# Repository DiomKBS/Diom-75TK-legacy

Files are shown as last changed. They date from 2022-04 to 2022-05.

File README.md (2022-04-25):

# full-board-shorter
a keyboard with 75% layout that has macrokeys and a numpad

## The current design:
current design

## You can visit the whiteboard over at Milanote:
Link --> [Whiteboard](https://app.milanote.com/1NjfUT1bPf1Z3v?p=4XtU1EYbywI)

pcb
pcb_back

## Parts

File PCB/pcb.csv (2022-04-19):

Source: | C:\Users\Philipp Bleimund\git\repository\Diom-75TK\PCB\pcb.kicad_sch
Date: | 20.04.2022 00:11:18
Tool: | Eeschema (6.0.4)
Generator: | C:\Program Files\KiCad\6.0\bin\scripting\plugins/bom_csv_grouped_by_value.py
Component Count: | 324
Individual Components:
Item | Qty | Reference(s) | Value | LibPart | Footprint | Datasheet | Item | LCSC | Name
 |  | C1 | 10u | Device:C_Small | Capacitor_SMD:C_0805_2012Metric | ~
 |  | C2 | 0.1uF | Device:C_Small | Capacitor_SMD:C_0805_2012Metric | ~
 |  | C3 | 0.1uF | Device:C_Small | Capacitor_SMD:C_0805_2012Metric | ~
 |  | C4 | 0.1uF | Device:C_Small | Capacitor_SMD:C_0805_2012Metric | ~
 |  | C5 | 22pF | Device:C_Small | Capacitor_SMD:C_0805_2012Metric | ~
 |  | C6 | 22pF | Device:C_Small | Capacitor_SMD:C_0805_2012Metric | ~
 |  | C7 | 10uF | Device:C_Small | Capacitor_SMD:C_0805_2012Metric | ~
 |  | C8 | 1uF | Device:C_Small | Capacitor_SMD:C_0805_2012Metric | ~
 |  | D1 | 1.25V@150mA | led:D_Small | led:D_SOD-123 | ~ | 1N4148W | https://lcsc.com/product-detail/Switching-Diode_GOODWORK-1N4148W_C909967.html | Esc
 |  | D2 | 1.25V@150mA | Device:D_Small | led:D_SOD-123 | ~ |  |  | ^
 |  | D3 | 1.25V@150mA | Device:D_Small | led:D_SOD-123 | ~ |  |  | Tab
 |  | D4 | 1.25V@150mA | Device:D_Small | led:D_SOD-123 | ~ |  |  | Caps
 |  | D5 | 1.25V@150mA | Device:D_Small | led:D_SOD-123 | ~ |  |  | Shift
 |  | D6 | 1.25V@150mA | Device:D_Small | led:D_SOD-123 | ~ |  |  | Ctrl
 |  | D7 | 1.25V@150mA | Device:D_Small | led:D_SOD-123 | ~ |  |  | 1
 |  | D8 | 1.25V@150mA | Device:D_Small | led:D_SOD-123 | ~ |  |  | Q
 |  | D9 | 1.25V@150mA | Device:D_Small | led:D_SOD-123 | ~ |  |  | A
 |  | D10 | 1.25V@150mA | Device:D_Small | led:D_SOD-123 | ~ |  |  | <
 |  | D11 | 1.25V@150mA | Device:D_Small | led:D_SOD-123 | ~ |  |  | Win
 |  | D12 | 1.25V@150mA | Device:D_Small | led:D_SOD-123 | ~ |  |  | F1
 |  | D13 | 1.25V@150mA | Device:D_Small | led:D_SOD-123 | ~ |  |  | 2
 |  | D14 | 1.25V@150mA | Device:D_Small | led:D_SOD-123 | ~ |  |  | W
 |  | D15 | 1.25V@150mA | Device:D_Small | led:D_SOD-123 | ~ |  |  | S
 |  | D16 | 1.25V@150mA | Device:D_Small | led:D_SOD-123 | ~ |  |  | Y
 |  | D17 | 1.25V@150mA | Device:D_Small | led:D_SOD-123 | ~ |  |  | Alt
 |  | D18 | 1.25V@150mA | Device:D_Small | led:D_SOD-123 | ~ |  |  | F2
 |  | D19 | 1.25V@150mA | Device:D_Small | led:D_SOD-123 | ~ |  |  | 3
 |  | D20 | 1.25V@150mA | Device:D_Small | led:D_SOD-123 | ~ |  |  | E
 |  | D21 | 1.25V@150mA | Device:D_Small | led:D_SOD-123 | ~ |  |  | D
 |  | D22 | 1.25V@150mA | Device:D_Small | led:D_SOD-123 | ~ |  |  | X
 |  | D23 | 1.25V@150mA | Device:D_Small | led:D_SOD-123 | ~ |  |  | F3
 |  | D24 | 1.25V@150mA | Device:D_Small | led:D_SOD-123 | ~ |  |  | 4
 |  | D25 | 1.25V@150mA | Device:D_Small | led:D_SOD-123 | ~ |  |  | R
 |  | D26 | 1.25V@150mA | Device:D_Small | led:D_SOD-123 | ~ |  |  | F
 |  | D27 | 1.25V@150mA | Device:D_Small | led:D_SOD-123 | ~ |  |  | C
 |  | D28 | 1.25V@150mA | Device:D_Small | led:D_SOD-123 | ~ |  |  | F4
 |  | D29 | 1.25V@150mA | Device:D_Small | led:D_SOD-123 | ~ |  |  | 5
 |  | D30 | 1.25V@150mA | Device:D_Small | led:D_SOD-123 | ~ |  |  | T
 |  | D31 | 1.25V@150mA | Device:D_Small | led:D_SOD-123 | ~ |  |  | G
 |  | D32 | 1.25V@150mA | Device:D_Small | led:D_SOD-123 | ~ |  |  | V
 |  | D33 | 1.25V@150mA | Device:D_Small | led:D_SOD-123 | ~ |  |  | F5
 |  | D34 | 1.25V@150mA | Device:D_Small | led:D_SOD-123 | ~ |  |  | 6
 |  | D35 | 1.25V@150mA | Device:D_Small | led:D_SOD-123 | ~ |  |  | Z
 |  | D36 | 1.25V@150mA | Device:D_Small | led:D_SOD-123 | ~ |  |  | H
 |  | D37 | 1.25V@150mA | Device:D_Small | led:D_SOD-123 | ~ |  |  | B
 |  | D38 | 1.25V@150mA | Device:D_Small | led:D_SOD-123 | ~ |  |  | Space
 |  | D39 | 1.25V@150mA | Device:D_Small | led:D_SOD-123 | ~ |  |  | F6
 |  | D40 | 1.25V@150mA | Device:D_Small | led:D_SOD-123 | ~ |  |  | 7
 |  | D41 | 1.25V@150mA | Device:D_Small | led:D_SOD-123 | ~ |  |  | U
 |  | D42 | 1.25V@150mA | Device:D_Small | led:D_SOD-123 | ~ |  |  | J
 |  | D43 | 1.25V@150mA | Device:D_Small | led:D_SOD-123 | ~ |  |  | N
 |  | D44 | 1.25V@150mA | Device:D_Small | led:D_SOD-123 | ~ |  |  | F7
 |  | D45 | 1.25V@150mA | Device:D_Small | led:D_SOD-123 | ~ |  |  | 8
 |  | D46 | 1.25V@150mA | Device:D_Small | led:D_SOD-123 | ~ |  |  | I
 |  | D47 | 1.25V@150mA | Device:D_Small | led:D_SOD-123 | ~ |  |  | K
 |  | D48 | 1.25V@150mA | Device:D_Small | led:D_SOD-123 | ~ |  |  | M
 |  | D49 | 1.25V@150mA | Device:D_Small | led:D_SOD-123 | ~ |  |  | F8
 |  | D50 | 1.25V@150mA | Device:D_Small | led:D_SOD-123 | ~ |  |  | 9
 |  | D51 | 1.25V@150mA | Device:D_Small | led:D_SOD-123 | ~ |  |  | O
 |  | D52 | 1.25V@150mA | Device:D_Small | led:D_SOD-123 | ~ |  |  | L
 |  | D53 | 1.25V@150mA | Device:D_Small | led:D_SOD-123 | ~ |  |  | ,
 |  | D54 | 1.25V@150mA | Device:D_Small | led:D_SOD-123 | ~ |  |  | F9
 |  | D55 | 1.25V@150mA | Device:D_Small | led:D_SOD-123 | ~ |  |  | 0
 |  | D56 | 1.25V@150mA | Device:D_Small | led:D_SOD-123 | ~ |  |  | P
 |  | D57 | 1.25V@150mA | Device:D_Small | led:D_SOD-123 | ~ |  |  | Ö
 |  | D58 | 1.25V@150mA | Device:D_Small | led:D_SOD-123 | ~ |  |  | .
 |  | D59 | 1.25V@150mA | Device:D_Small | led:D_SOD-123 | ~ |  |  | AltGr
 |  | D60 | 1.25V@150mA | Device:D_Small | led:D_SOD-123 | ~ |  |  | F10
 |  | D61 | 1.25V@150mA | Device:D_Small | led:D_SOD-123 | ~ |  |  | ß
 |  | D62 | 1.25V@150mA | Device:D_Small | led:D_SOD-123 | ~ |  |  | Ü
 |  | D63 | 1.25V@150mA | Device:D_Small | led:D_SOD-123 | ~ |  |  | Ä
 |  | D64 | 1.25V@150mA | Device:D_Small | led:D_SOD-123 | ~ |  |  | -
 |  | D65 | 1.25V@150mA | Device:D_Small | led:D_SOD-123 | ~ |  |  | Fn
 |  | D66 | 1.25V@150mA | Device:D_Small | led:D_SOD-123 | ~ |  |  | F11
 |  | D67 | 1.25V@150mA | Device:D_Small | led:D_SOD-123 | ~ |  |  | ´
 |  | D68 | 1.25V@150mA | Device:D_Small | led:D_SOD-123 | ~ |  |  | +
 |  | D69 | 1.25V@150mA | Device:D_Small | led:D_SOD-123 | ~ |  |  | #
 |  | D70 | 1.25V@150mA | Device:D_Small | led:D_SOD-123 | ~ |  |  | Shift
 |  | D71 | 1.25V@150mA | Device:D_Small | led:D_SOD-123 | ~ |  |  | Win
 |  | D72 | 1.25V@150mA | Device:D_Small | led:D_SOD-123 | ~ |  |  | F12
 |  | D73 | 1.25V@150mA | Device:D_Small | led:D_SOD-123 | ~ |  |  | Back
 |  | D74 | 1.25V@150mA | Device:D_Small | led:D_SOD-123 | ~ |  |  | Enter
 |  | D75 | 1.25V@150mA | Device:D_Small | led:D_SOD-123 | ~ |  |  | Left
 |  | D76 | 1.25V@150mA | Device:D_Small | led:D_SOD-123 | ~ |  |  | Up
 |  | D77 | 1.25V@150mA | Device:D_Small | led:D_SOD-123 | ~ |  |  | Down
 |  | D78 | 1.25V@150mA | Device:D_Small | led:D_SOD-123 | ~ |  |  | Rigth
 |  | D79 | 1.25V@150mA | Device:D_Small | led:D_SOD-123 | ~ |  |  | Druck
 |  | D80 | 1.25V@150mA | Device:D_Small | led:D_SOD-123 | ~ |  |  | Insert
 |  | D81 | 1.25V@150mA | Device:D_Small | led:D_SOD-123 | ~ |  |  | Del
 |  | D82 | 1.25V@150mA | Device:D_Small | led:D_SOD-123 | ~ |  |  | PgUp
 |  | D83 | 1.25V@150mA | Device:D_Small | led:D_SOD-123 | ~ |  |  | PgDn
 |  | D84 | 1.25V@150mA | Device:D_Small | led:D_SOD-123 | ~ |  |  | NumLock
 |  | D85 | 1.25V@150mA | Device:D_Small | led:D_SOD-123 | ~ |  |  | 7
 |  | D86 | 1.25V@150mA | Device:D_Small | led:D_SOD-123 | ~ |  |  | 4
 |  | D87 | 1.25V@150mA | Device:D_Small | led:D_SOD-123 | ~ |  |  | 1
 |  | D88 | 1.25V@150mA | Device:D_Small | led:D_SOD-123 | ~ |  |  | 0
 |  | D89 | 1.25V@150mA | Device:D_Small | led:D_SOD-123 | ~ |  |  | /
 |  | D90 | 1.25V@150mA | Device:D_Small | led:D_SOD-123 | ~ |  |  | 8
 |  | D91 | 1.25V@150mA | Device:D_Small | led:D_SOD-123 | ~ |  |  | 5
 |  | D92 | 1.25V@150mA | Device:D_Small | led:D_SOD-123 | ~ |  |  | 2
 |  | D93 | 1.25V@150mA | Device:D_Small | led:D_SOD-123 | ~ |  |  | ,
 |  | D94 | 1.25V@150mA | Device:D_Small | led:D_SOD-123 | ~ |  |  | *
 |  | D95 | 1.25V@150mA | Device:D_Small | led:D_SOD-123 | ~ |  |  | 9
 |  | D96 | 1.25V@150mA | Device:D_Small | led:D_SOD-123 | ~ |  |  | 6
 |  | D97 | 1.25V@150mA | Device:D_Small | led:D_SOD-123 | ~ |  |  | 3
 |  | D98 | 1.25V@150mA | Device:D_Small | led:D_SOD-123 | ~ |  |  | -
 |  | D99 | 1.25V@150mA | Device:D_Small | led:D_SOD-123 | ~ |  |  | +
 |  | D100 | 1.25V@150mA | Device:D_Small | led:D_SOD-123 | ~ |  |  | Enter
 |  | D101 | SK6812MINI | LED:SK6812MINI | led:SK6812MINI_3.5x3.7mm_SMD-Flipped-Back | https://cdn-shop.adafruit.com/product-files/2686/SK6812MINI_REV.01-1-2.pdf
 |  | D102 | SK6812MINI | LED:SK6812MINI | led:SK6812MINI_3.5x3.7mm_SMD-Flipped-Back | https://cdn-shop.adafruit.com/product-files/2686/SK6812MINI_REV.01-1-2.pdf
 |  | D103 | SK6812MINI | LED:SK6812MINI | led:SK6812MINI_3.5x3.7mm_SMD-Flipped-Back | https://cdn-shop.adafruit.com/product-files/2686/SK6812MINI_REV.01-1-2.pdf
 |  | D104 | SK6812MINI | LED:SK6812MINI | led:SK6812MINI_3.5x3.7mm_SMD-Flipped-Back | https://cdn-shop.adafruit.com/product-files/2686/SK6812MINI_REV.01-1-2.pdf
 |  | D105 | SK6812MINI | LED:SK6812MINI | led:SK6812MINI_3.5x3.7mm_SMD-Flipped-Back | https://cdn-shop.adafruit.com/product-files/2686/SK6812MINI_REV.01-1-2.pdf
 |  | D106 | SK6812MINI | LED:SK6812MINI | led:SK6812MINI_3.5x3.7mm_SMD-Flipped-Back | https://cdn-shop.adafruit.com/product-files/2686/SK6812MINI_REV.01-1-2.pdf
 |  | D107 | SK6812MINI | LED:SK6812MINI | led:SK6812MINI_3.5x3.7mm_SMD-Flipped-Back | https://cdn-shop.adafruit.com/product-files/2686/SK6812MINI_REV.01-1-2.pdf
 |  | D108 | SK6812MINI | LED:SK6812MINI | led:SK6812MINI_3.5x3.7mm_SMD-Flipped-Back | https://cdn-shop.adafruit.com/product-files/2686/SK6812MINI_REV.01-1-2.pdf
 |  | D109 | SK6812MINI | LED:SK6812MINI | led:SK6812MINI_3.5x3.7mm_SMD-Flipped-Back | https://cdn-shop.adafruit.com/product-files/2686/SK6812MINI_REV.01-1-2.pdf
 |  | D110 | SK6812MINI | LED:SK6812MINI | led:SK6812MINI_3.5x3.7mm_SMD-Flipped-Back | https://cdn-shop.adafruit.com/product-files/2686/SK6812MINI_REV.01-1-2.pdf
 |  | D111 | SK6812MINI | LED:SK6812MINI | led:SK6812MINI_3.5x3.7mm_SMD-Flipped-Back | https://cdn-shop.adafruit.com/product-files/2686/SK6812MINI_REV.01-1-2.pdf
 |  | D112 | SK6812MINI | LED:SK6812MINI | led:SK6812MINI_3.5x3.7mm_SMD-Flipped-Back | https://cdn-shop.adafruit.com/product-files/2686/SK6812MINI_REV.01-1-2.pdf
 |  | D113 | SK6812MINI | LED:SK6812MINI | led:SK6812MINI_3.5x3.7mm_SMD-Flipped-Back | https://cdn-shop.adafruit.com/product-files/2686/SK6812MINI_REV.01-1-2.pdf
 |  | D114 | SK6812MINI | LED:SK6812MINI | led:SK6812MINI_3.5x3.7mm_SMD-Flipped-Back | https://cdn-shop.adafruit.com/product-files/2686/SK6812MINI_REV.01-1-2.pdf
 |  | D115 | SK6812MINI | LED:SK6812MINI | led:SK6812MINI_3.5x3.7mm_SMD-Flipped-Back | https://cdn-shop.adafruit.com/product-files/2686/SK6812MINI_REV.01-1-2.pdf
 |  | D116 | SK6812MINI | LED:SK6812MINI | led:SK6812MINI_3.5x3.7mm_SMD-Flipped-Back | https://cdn-shop.adafruit.com/product-files/2686/SK6812MINI_REV.01-1-2.pdf
 |  | D117 | SK6812MINI | LED:SK6812MINI | led:SK6812MINI_3.5x3.7mm_SMD-Flipped-Back | https://cdn-shop.adafruit.com/product-files/2686/SK6812MINI_REV.01-1-2.pdf
 |  | D118 | SK6812MINI | LED:SK6812MINI | led:SK6812MINI_3.5x3.7mm_SMD-Flipped-Back | https://cdn-shop.adafruit.com/product-files/2686/SK6812MINI_REV.01-1-2.pdf
 |  | D119 | SK6812MINI | LED:SK6812MINI | led:SK6812MINI_3.5x3.7mm_SMD-Flipped-Back | https://cdn-shop.adafruit.com/product-files/2686/SK6812MINI_REV.01-1-2.pdf
 |  | D120 | SK6812MINI | LED:SK6812MINI | led:SK6812MINI_3.5x3.7mm_SMD-Flipped-Back | https://cdn-shop.adafruit.com/product-files/2686/SK6812MINI_REV.01-1-2.pdf
 |  | D121 | SK6812MINI | LED:SK6812MINI | led:SK6812MINI_3.5x3.7mm_SMD-Flipped-Back | https://cdn-shop.adafruit.com/product-files/2686/SK6812MINI_REV.01-1-2.pdf
 |  | D122 | SK6812MINI | LED:SK6812MINI | led:SK6812MINI_3.5x3.7mm_SMD-Flipped-Back | https://cdn-shop.adafruit.com/product-files/2686/SK6812MINI_REV.01-1-2.pdf
 |  | D123 | SK6812MINI | LED:SK6812MINI | led:SK6812MINI_3.5x3.7mm_SMD-Flipped-Back | https://cdn-shop.adafruit.com/product-files/2686/SK6812MINI_REV.01-1-2.pdf
 |  | D124 | SK6812MINI | LED:SK6812MINI | led:SK6812MINI_3.5x3.7mm_SMD-Flipped-Back | https://cdn-shop.adafruit.com/product-files/2686/SK6812MINI_REV.01-1-2.pdf
 |  | D125 | SK6812MINI | LED:SK6812MINI | led:SK6812MINI_3.5x3.7mm_SMD-Flipped-Back | https://cdn-shop.adafruit.com/product-files/2686/SK6812MINI_REV.01-1-2.pdf
 |  | D126 | SK6812MINI | LED:SK6812MINI | led:SK6812MINI_3.5x3.7mm_SMD-Flipped-Back | https://cdn-shop.adafruit.com/product-files/2686/SK6812MINI_REV.01-1-2.pdf
 |  | D127 | SK6812MINI | LED:SK6812MINI | led:SK6812MINI_3.5x3.7mm_SMD-Flipped-Back | https://cdn-shop.adafruit.com/product-files/2686/SK6812MINI_REV.01-1-2.pdf
 |  | D128 | SK6812MINI | LED:SK6812MINI | led:SK6812MINI_3.5x3.7mm_SMD-Flipped-Back | https://cdn-shop.adafruit.com/product-files/2686/SK6812MINI_REV.01-1-2.pdf
 |  | D129 | SK6812MINI | LED:SK6812MINI | led:SK6812MINI_3.5x3.7mm_SMD-Flipped-Back | https://cdn-shop.adafruit.com/product-files/2686/SK6812MINI_REV.01-1-2.pdf
 |  | D130 | SK6812MINI | LED:SK6812MINI | led:SK6812MINI_3.5x3.7mm_SMD-Flipped-Back | https://cdn-shop.adafruit.com/product-files/2686/SK6812MINI_REV.01-1-2.pdf
 |  | D131 | SK6812MINI | LED:SK6812MINI | led:SK6812MINI_3.5x3.7mm_SMD-Flipped-Back | https://cdn-shop.adafruit.com/product-files/2686/SK6812MINI_REV.01-1-2.pdf
 |  | D132 | SK6812MINI | LED:SK6812MINI | led:SK6812MINI_3.5x3.7mm_SMD-Flipped-Back | https://cdn-shop.adafruit.com/product-files/2686/SK6812MINI_REV.01-1-2.pdf
 |  | D133 | SK6812MINI | LED:SK6812MINI | led:SK6812MINI_3.5x3.7mm_SMD-Flipped-Back | https://cdn-shop.adafruit.com/product-files/2686/SK6812MINI_REV.01-1-2.pdf
 |  | D134 | SK6812MINI | LED:SK6812MINI | led:SK6812MINI_3.5x3.7mm_SMD-Flipped-Back | https://cdn-shop.adafruit.com/product-files/2686/SK6812MINI_REV.01-1-2.pdf
 |  | D135 | SK6812MINI | LED:SK6812MINI | led:SK6812MINI_3.5x3.7mm_SMD-Flipped-Back | https://cdn-shop.adafruit.com/product-files/2686/SK6812MINI_REV.01-1-2.pdf
 |  | D136 | SK6812MINI | LED:SK6812MINI | led:SK6812MINI_3.5x3.7mm_SMD-Flipped-Back | https://cdn-shop.adafruit.com/product-files/2686/SK6812MINI_REV.01-1-2.pdf
 |  | D137 | SK6812MINI | LED:SK6812MINI | led:SK6812MINI_3.5x3.7mm_SMD-Flipped-Back | https://cdn-shop.adafruit.com/product-files/2686/SK6812MINI_REV.01-1-2.pdf
 |  | D138 | SK6812MINI | LED:SK6812MINI | led:SK6812MINI_3.5x3.7mm_SMD-Flipped-Back | https://cdn-shop.adafruit.com/product-files/2686/SK6812MINI_REV.01-1-2.pdf
 |  | D139 | SK6812MINI | LED:SK6812MINI | led:SK6812MINI_3.5x3.7mm_SMD-Flipped-Back | https://cdn-shop.adafruit.com/product-files/2686/SK6812MINI_REV.01-1-2.pdf
 |  | D140 | SK6812MINI | LED:SK6812MINI | led:SK6812MINI_3.5x3.7mm_SMD-Flipped-Back | https://cdn-shop.adafruit.com/product-files/2686/SK6812MINI_REV.01-1-2.pdf
 |  | D141 | SK6812MINI | LED:SK6812MINI | led:SK6812MINI_3.5x3.7mm_SMD-Flipped-Back | https://cdn-shop.adafruit.com/product-files/2686/SK6812MINI_REV.01-1-2.pdf
 |  | D142 | SK6812MINI | LED:SK6812MINI | led:SK6812MINI_3.5x3.7mm_SMD-Flipped-Back | https://cdn-shop.adafruit.com/product-files/2686/SK6812MINI_REV.01-1-2.pdf
 |  | D143 | SK6812MINI | LED:SK6812MINI | led:SK6812MINI_3.5x3.7mm_SMD-Flipped-Back | https://cdn-shop.adafruit.com/product-files/2686/SK6812MINI_REV.01-1-2.pdf
 |  | D144 | SK6812MINI | LED:SK6812MINI | led:SK6812MINI_3.5x3.7mm_SMD-Flipped-Back | https://cdn-shop.adafruit.com/product-files/2686/SK6812MINI_REV.01-1-2.pdf
 |  | D145 | SK6812MINI | LED:SK6812MINI | led:SK6812MINI_3.5x3.7mm_SMD-Flipped-Back | https://cdn-shop.adafruit.com/product-files/2686/SK6812MINI_REV.01-1-2.pdf
 |  | D146 | SK6812MINI | LED:SK6812MINI | led:SK6812MINI_3.5x3.7mm_SMD-Flipped-Back | https://cdn-shop.adafruit.com/product-files/2686/SK6812MINI_REV.01-1-2.pdf
 |  | D147 | SK6812MINI | LED:SK6812MINI | led:SK6812MINI_3.5x3.7mm_SMD-Flipped-Back | https://cdn-shop.adafruit.com/product-files/2686/SK6812MINI_REV.01-1-2.pdf
 |  | D148 | SK6812MINI | LED:SK6812MINI | led:SK6812MINI_3.5x3.7mm_SMD-Flipped-Back | https://cdn-shop.adafruit.com/product-files/2686/SK6812MINI_REV.01-1-2.pdf
 |  | D149 | SK6812MINI | LED:SK6812MINI | led:SK6812MINI_3.5x3.7mm_SMD-Flipped-Back | https://cdn-shop.adafruit.com/product-files/2686/SK6812MINI_REV.01-1-2.pdf
 |  | D150 | SK6812MINI | LED:SK6812MINI | led:SK6812MINI_3.5x3.7mm_SMD-Flipped-Back | https://cdn-shop.adafruit.com/product-files/2686/SK6812MINI_REV.01-1-2.pdf
 |  | D151 | SK6812MINI | LED:SK6812MINI | led:SK6812MINI_3.5x3.7mm_SMD-Flipped-Back | https://cdn-shop.adafruit.com/product-files/2686/SK6812MINI_REV.01-1-2.pdf
 |  | D152 | SK6812MINI | LED:SK6812MINI | led:SK6812MINI_3.5x3.7mm_SMD-Flipped-Back | https://cdn-shop.adafruit.com/product-files/2686/SK6812MINI_REV.01-1-2.pdf
 |  | D153 | SK6812MINI | LED:SK6812MINI | led:SK6812MINI_3.5x3.7mm_SMD-Flipped-Back | https://cdn-shop.adafruit.com/product-files/2686/SK6812MINI_REV.01-1-2.pdf
 |  | D154 | SK6812MINI | LED:SK6812MINI | led:SK6812MINI_3.5x3.7mm_SMD-Flipped-Back | https://cdn-shop.adafruit.com/product-files/2686/SK6812MINI_REV.01-1-2.pdf
 |  | D155 | SK6812MINI | LED:SK6812MINI | led:SK6812MINI_3.5x3.7mm_SMD-Flipped-Back | https://cdn-shop.adafruit.com/product-files/2686/SK6812MINI_REV.01-1-2.pdf
 |  | D156 | SK6812MINI | LED:SK6812MINI | led:SK6812MINI_3.5x3.7mm_SMD-Flipped-Back | https://cdn-shop.adafruit.com/product-files/2686/SK6812MINI_REV.01-1-2.pdf
 |  | D157 | SK6812MINI | LED:SK6812MINI | led:SK6812MINI_3.5x3.7mm_SMD-Flipped-Back | https://cdn-shop.adafruit.com/product-files/2686/SK6812MINI_REV.01-1-2.pdf
 |  | D158 | SK6812MINI | LED:SK6812MINI | led:SK6812MINI_3.5x3.7mm_SMD-Flipped-Back | https://cdn-shop.adafruit.com/product-files/2686/SK6812MINI_REV.01-1-2.pdf
 |  | D159 | SK6812MINI | LED:SK6812MINI | led:SK6812MINI_3.5x3.7mm_SMD-Flipped-Back | https://cdn-shop.adafruit.com/product-files/2686/SK6812MINI_REV.01-1-2.pdf
 |  | D160 | SK6812MINI | LED:SK6812MINI | led:SK6812MINI_3.5x3.7mm_SMD-Flipped-Back | https://cdn-shop.adafruit.com/product-files/2686/SK6812MINI_REV.01-1-2.pdf
 |  | D161 | SK6812MINI | LED:SK6812MINI | led:SK6812MINI_3.5x3.7mm_SMD-Flipped-Back | https://cdn-shop.adafruit.com/product-files/2686/SK6812MINI_REV.01-1-2.pdf
 |  | D162 | SK6812MINI | LED:SK6812MINI | led:SK6812MINI_3.5x3.7mm_SMD-Flipped-Back | https://cdn-shop.adafruit.com/product-files/2686/SK6812MINI_REV.01-1-2.pdf
 |  | D163 | SK6812MINI | LED:SK6812MINI | led:SK6812MINI_3.5x3.7mm_SMD-Flipped-Back | https://cdn-shop.adafruit.com/product-files/2686/SK6812MINI_REV.01-1-2.pdf
 |  | D164 | SK6812MINI | LED:SK6812MINI | led:SK6812MINI_3.5x3.7mm_SMD-Flipped-Back | https://cdn-shop.adafruit.com/product-files/2686/SK6812MINI_REV.01-1-2.pdf
 |  | D165 | SK6812MINI | LED:SK6812MINI | led:SK6812MINI_3.5x3.7mm_SMD-Flipped-Back | https://cdn-shop.adafruit.com/product-files/2686/SK6812MINI_REV.01-1-2.pdf
 |  | D166 | SK6812MINI | LED:SK6812MINI | led:SK6812MINI_3.5x3.7mm_SMD-Flipped-Back | https://cdn-shop.adafruit.com/product-files/2686/SK6812MINI_REV.01-1-2.pdf
 |  | D167 | SK6812MINI | LED:SK6812MINI | led:SK6812MINI_3.5x3.7mm_SMD-Flipped-Back | https://cdn-shop.adafruit.com/product-files/2686/SK6812MINI_REV.01-1-2.pdf
 |  | D168 | SK6812MINI | LED:SK6812MINI | led:SK6812MINI_3.5x3.7mm_SMD-Flipped-Back | https://cdn-shop.adafruit.com/product-files/2686/SK6812MINI_REV.01-1-2.pdf
 |  | D169 | SK6812MINI | LED:SK6812MINI | led:SK6812MINI_3.5x3.7mm_SMD-Flipped-Back | https://cdn-shop.adafruit.com/product-files/2686/SK6812MINI_REV.01-1-2.pdf
 |  | D170 | SK6812MINI | LED:SK6812MINI | led:SK6812MINI_3.5x3.7mm_SMD-Flipped-Back | https://cdn-shop.adafruit.com/product-files/2686/SK6812MINI_REV.01-1-2.pdf
 |  | D171 | SK6812MINI | LED:SK6812MINI | led:SK6812MINI_3.5x3.7mm_SMD-Flipped-Back | https://cdn-shop.adafruit.com/product-files/2686/SK6812MINI_REV.01-1-2.pdf
 |  | D172 | SK6812MINI | LED:SK6812MINI | led:SK6812MINI_3.5x3.7mm_SMD-Flipped-Back | https://cdn-shop.adafruit.com/product-files/2686/SK6812MINI_REV.01-1-2.pdf
 |  | D173 | SK6812MINI | LED:SK6812MINI | led:SK6812MINI_3.5x3.7mm_SMD-Flipped-Back | https://cdn-shop.adafruit.com/product-files/2686/SK6812MINI_REV.01-1-2.pdf
 |  | D174 | SK6812MINI | LED:SK6812MINI | led:SK6812MINI_3.5x3.7mm_SMD-Flipped-Back | https://cdn-shop.adafruit.com/product-files/2686/SK6812MINI_REV.01-1-2.pdf
 |  | D175 | SK6812MINI | LED:SK6812MINI | led:SK6812MINI_3.5x3.7mm_SMD-Flipped-Back | https://cdn-shop.adafruit.com/product-files/2686/SK6812MINI_REV.01-1-2.pdf
 |  | D176 | SK6812MINI | LED:SK6812MINI | led:SK6812MINI_3.5x3.7mm_SMD-Flipped-Back | https://cdn-shop.adafruit.com/product-files/2686/SK6812MINI_REV.01-1-2.pdf
 |  | D177 | SK6812MINI | LED:SK6812MINI | led:SK6812MINI_3.5x3.7mm_SMD-Flipped-Back | https://cdn-shop.adafruit.com/product-files/2686/SK6812MINI_REV.01-1-2.pdf
 |  | D178 | SK6812MINI | LED:SK6812MINI | led:SK6812MINI_3.5x3.7mm_SMD-Flipped-Back | https://cdn-shop.adafruit.com/product-files/2686/SK6812MINI_REV.01-1-2.pdf
 |  | D179 | SK6812MINI | LED:SK6812MINI | led:SK6812MINI_3.5x3.7mm_SMD-Flipped-Back | https://cdn-shop.adafruit.com/product-files/2686/SK6812MINI_REV.01-1-2.pdf
 |  | D180 | SK6812MINI | LED:SK6812MINI | led:SK6812MINI_3.5x3.7mm_SMD-Flipped-Back | https://cdn-shop.adafruit.com/product-files/2686/SK6812MINI_REV.01-1-2.pdf
 |  | D181 | SK6812MINI | LED:SK6812MINI | led:SK6812MINI_3.5x3.7mm_SMD-Flipped-Back | https://cdn-shop.adafruit.com/product-files/2686/SK6812MINI_REV.01-1-2.pdf
 |  | D182 | SK6812MINI | LED:SK6812MINI | led:SK6812MINI_3.5x3.7mm_SMD-Flipped-Back | https://cdn-shop.adafruit.com/product-files/2686/SK6812MINI_REV.01-1-2.pdf
 |  | D183 | SK6812MINI | LED:SK6812MINI | led:SK6812MINI_3.5x3.7mm_SMD-Flipped-Back | https://cdn-shop.adafruit.com/product-files/2686/SK6812MINI_REV.01-1-2.pdf
 |  | D184 | SK6812MINI | LED:SK6812MINI | led:SK6812MINI_3.5x3.7mm_SMD-Flipped-Back | https://cdn-shop.adafruit.com/product-files/2686/SK6812MINI_REV.01-1-2.pdf
 |  | D185 | SK6812MINI | LED:SK6812MINI | led:SK6812MINI_3.5x3.7mm_SMD-Flipped-Back | https://cdn-shop.adafruit.com/product-files/2686/SK6812MINI_REV.01-1-2.pdf
 |  | D186 | SK6812MINI | LED:SK6812MINI | led:SK6812MINI_3.5x3.7mm_SMD-Flipped-Back | https://cdn-shop.adafruit.com/product-files/2686/SK6812MINI_REV.01-1-2.pdf
 |  | D187 | SK6812MINI | LED:SK6812MINI | led:SK6812MINI_3.5x3.7mm_SMD-Flipped-Back | https://cdn-shop.adafruit.com/product-files/2686/SK6812MINI_REV.01-1-2.pdf
 |  | D188 | SK6812MINI | LED:SK6812MINI | led:SK6812MINI_3.5x3.7mm_SMD-Flipped-Back | https://cdn-shop.adafruit.com/product-files/2686/SK6812MINI_REV.01-1-2.pdf
 |  | D189 | SK6812MINI | LED:SK6812MINI | led:SK6812MINI_3.5x3.7mm_SMD-Flipped-Back | https://cdn-shop.adafruit.com/product-files/2686/SK6812MINI_REV.01-1-2.pdf
 |  | D190 | SK6812MINI | LED:SK6812MINI | led:SK6812MINI_3.5x3.7mm_SMD-Flipped-Back | https://cdn-shop.adafruit.com/product-files/2686/SK6812MINI_REV.01-1-2.pdf
 |  | D191 | SK6812MINI | LED:SK6812MINI | led:SK6812MINI_3.5x3.7mm_SMD-Flipped-Back | https://cdn-shop.adafruit.com/product-files/2686/SK6812MINI_REV.01-1-2.pdf
 |  | D192 | SK6812MINI | LED:SK6812MINI | led:SK6812MINI_3.5x3.7mm_SMD-Flipped-Back | https://cdn-shop.adafruit.com/product-files/2686/SK6812MINI_REV.01-1-2.pdf
 |  | D193 | SK6812MINI | LED:SK6812MINI | led:SK6812MINI_3.5x3.7mm_SMD-Flipped-Back | https://cdn-shop.adafruit.com/product-files/2686/SK6812MINI_REV.01-1-2.pdf
 |  | D194 | SK6812MINI | LED:SK6812MINI | led:SK6812MINI_3.5x3.7mm_SMD-Flipped-Back | https://cdn-shop.adafruit.com/product-files/2686/SK6812MINI_REV.01-1-2.pdf
 |  | D195 | SK6812MINI | LED:SK6812MINI | led:SK6812MINI_3.5x3.7mm_SMD-Flipped-Back | https://cdn-shop.adafruit.com/product-files/2686/SK6812MINI_REV.01-1-2.pdf
 |  | D196 | SK6812MINI | LED:SK6812MINI | led:SK6812MINI_3.5x3.7mm_SMD-Flipped-Back | https://cdn-shop.adafruit.com/product-files/2686/SK6812MINI_REV.01-1-2.pdf
 |  | D197 | SK6812MINI | LED:SK6812MINI | led:SK6812MINI_3.5x3.7mm_SMD-Flipped-Back | https://cdn-shop.adafruit.com/product-files/2686/SK6812MINI_REV.01-1-2.pdf
 |  | D198 | SK6812MINI | LED:SK6812MINI | led:SK6812MINI_3.5x3.7mm_SMD-Flipped-Back | https://cdn-shop.adafruit.com/product-files/2686/SK6812MINI_REV.01-1-2.pdf
 |  | D199 | SK6812MINI | LED:SK6812MINI | led:SK6812MINI_3.5x3.7mm_SMD-Flipped-Back | https://cdn-shop.adafruit.com/product-files/2686/SK6812MINI_REV.01-1-2.pdf
 |  | D200 | SK6812MINI | LED:SK6812MINI | led:SK6812MINI_3.5x3.7mm_SMD-Flipped-Back | https://cdn-shop.adafruit.com/product-files/2686/SK6812MINI_REV.01-1-2.pdf
 |  | F1 | 500mA | Device:Polyfuse_Small | Fuse:Fuse_1206_3216Metric | ~
 |  | FB1 | 600R | pcb-rescue:Ferrite_Bead_Small-Device | josh-passives-smt:Ferrite_Bead_0603
 |  | J1 | USB_C_Receptacle_USB2.0 | pcb-rescue:USB_C_Receptacle_USB2.0-Connector | Connector_USB:USB_C_Receptacle_HRO_TYPE-C-31-M-12 | https://www.usb.org/sites/default/files/documents/usb_type-c.zip
 |  | MX1 | MX-NoLED | pcb-rescue:MX-NoLED-MX_Alps_Hybrid | kailh-switches-hotswap:Kailh-Hotswap-1U
 |  | MX2 | MX-NoLED | pcb-rescue:MX-NoLED-MX_Alps_Hybrid | kailh-switches-hotswap:Kailh-Hotswap-1U
 |  | MX3 | MX-NoLED | pcb-rescue:MX-NoLED-MX_Alps_Hybrid | kailh-switches-hotswap:Kailh-Hotswap-1.5U
 |  | MX4 | MX-NoLED | pcb-rescue:MX-NoLED-MX_Alps_Hybrid | kailh-switches-hotswap:Kailh-Hotswap-1.75U
 |  | MX5 | MX-NoLED | pcb-rescue:MX-NoLED-MX_Alps_Hybrid | kailh-switches-hotswap:Kailh-Hotswap-1.25U
 |  | MX6 | MX-NoLED | pcb-rescue:MX-NoLED-MX_Alps_Hybrid | kailh-switches-hotswap:Kailh-Hotswap-1.5U
 |  | MX7 | MX-NoLED | pcb-rescue:MX-NoLED-MX_Alps_Hybrid | kailh-switches-hotswap:Kailh-Hotswap-1U
 |  | MX8 | MX-NoLED | pcb-rescue:MX-NoLED-MX_Alps_Hybrid | kailh-switches-hotswap:Kailh-Hotswap-1U
 |  | MX9 | MX-NoLED | pcb-rescue:MX-NoLED-MX_Alps_Hybrid | kailh-switches-hotswap:Kailh-Hotswap-1U
 |  | MX10 | MX-NoLED | pcb-rescue:MX-NoLED-MX_Alps_Hybrid | kailh-switches-hotswap:Kailh-Hotswap-1U
 |  | MX11 | MX-NoLED | pcb-rescue:MX-NoLED-MX_Alps_Hybrid | kailh-switches-hotswap:Kailh-Hotswap-1U
 |  | MX12 | MX-NoLED | pcb-rescue:MX-NoLED-MX_Alps_Hybrid | kailh-switches-hotswap:Kailh-Hotswap-1U
 |  | MX13 | MX-NoLED | pcb-rescue:MX-NoLED-MX_Alps_Hybrid | kailh-switches-hotswap:Kailh-Hotswap-1U
 |  | MX14 | MX-NoLED | pcb-rescue:MX-NoLED-MX_Alps_Hybrid | kailh-switches-hotswap:Kailh-Hotswap-1U
 |  | MX15 | MX-NoLED | pcb-rescue:MX-NoLED-MX_Alps_Hybrid | kailh-switches-hotswap:Kailh-Hotswap-1U
 |  | MX16 | MX-NoLED | pcb-rescue:MX-NoLED-MX_Alps_Hybrid | kailh-switches-hotswap:Kailh-Hotswap-1U
 |  | MX17 | MX-NoLED | pcb-rescue:MX-NoLED-MX_Alps_Hybrid | kailh-switches-hotswap:Kailh-Hotswap-1.25U
 |  | MX18 | MX-NoLED | pcb-rescue:MX-NoLED-MX_Alps_Hybrid | kailh-switches-hotswap:Kailh-Hotswap-1U
 |  | MX19 | MX-NoLED | pcb-rescue:MX-NoLED-MX_Alps_Hybrid | kailh-switches-hotswap:Kailh-Hotswap-1U
 |  | MX20 | MX-NoLED | pcb-rescue:MX-NoLED-MX_Alps_Hybrid | kailh-switches-hotswap:Kailh-Hotswap-1U
 |  | MX21 | MX-NoLED | pcb-rescue:MX-NoLED-MX_Alps_Hybrid | kailh-switches-hotswap:Kailh-Hotswap-1U
 |  | MX22 | MX-NoLED | pcb-rescue:MX-NoLED-MX_Alps_Hybrid | kailh-switches-hotswap:Kailh-Hotswap-1U
 |  | MX23 | MX-NoLED | pcb-rescue:MX-NoLED-MX_Alps_Hybrid | kailh-switches-hotswap:Kailh-Hotswap-1U
 |  | MX24 | MX-NoLED | pcb-rescue:MX-NoLED-MX_Alps_Hybrid | kailh-switches-hotswap:Kailh-Hotswap-1U
 |  | MX25 | MX-NoLED | pcb-rescue:MX-NoLED-MX_Alps_Hybrid | kailh-switches-hotswap:Kailh-Hotswap-1U
 |  | MX26 | MX-NoLED | pcb-rescue:MX-NoLED-MX_Alps_Hybrid | kailh-switches-hotswap:Kailh-Hotswap-1U
 |  | MX27 | MX-NoLED | pcb-rescue:MX-NoLED-MX_Alps_Hybrid | kailh-switches-hotswap:Kailh-Hotswap-1U
 |  | MX28 | MX-NoLED | pcb-rescue:MX-NoLED-MX_Alps_Hybrid | kailh-switches-hotswap:Kailh-Hotswap-1U
 |  | MX29 | MX-NoLED | pcb-rescue:MX-NoLED-MX_Alps_Hybrid | kailh-switches-hotswap:Kailh-Hotswap-1U
 |  | MX30 | MX-NoLED | pcb-rescue:MX-NoLED-MX_Alps_Hybrid | kailh-switches-hotswap:Kailh-Hotswap-1U
 |  | MX31 | MX-NoLED | pcb-rescue:MX-NoLED-MX_Alps_Hybrid | kailh-switches-hotswap:Kailh-Hotswap-1U
 |  | MX32 | MX-NoLED | pcb-rescue:MX-NoLED-MX_Alps_Hybrid | kailh-switches-hotswap:Kailh-Hotswap-1U
 |  | MX33 | MX-NoLED | pcb-rescue:MX-NoLED-MX_Alps_Hybrid | kailh-switches-hotswap:Kailh-Hotswap-1U
 |  | MX34 | MX-NoLED | pcb-rescue:MX-NoLED-MX_Alps_Hybrid | kailh-switches-hotswap:Kailh-Hotswap-1U
 |  | MX35 | MX-NoLED | pcb-rescue:MX-NoLED-MX_Alps_Hybrid | kailh-switches-hotswap:Kailh-Hotswap-1U
 |  | MX36 | MX-NoLED | pcb-rescue:MX-NoLED-MX_Alps_Hybrid | kailh-switches-hotswap:Kailh-Hotswap-1U
 |  | MX37 | MX-NoLED | pcb-rescue:MX-NoLED-MX_Alps_Hybrid | kailh-switches-hotswap:Kailh-Hotswap-1U
 |  | MX38 | MX-NoLED | pcb-rescue:MX-NoLED-MX_Alps_Hybrid | kailh-switches-hotswap:Kailh-Hotswap-6U
 |  | MX39 | MX-NoLED | pcb-rescue:MX-NoLED-MX_Alps_Hybrid | kailh-switches-hotswap:Kailh-Hotswap-1U
 |  | MX40 | MX-NoLED | pcb-rescue:MX-NoLED-MX_Alps_Hybrid | kailh-switches-hotswap:Kailh-Hotswap-1U
 |  | MX41 | MX-NoLED | pcb-rescue:MX-NoLED-MX_Alps_Hybrid | kailh-switches-hotswap:Kailh-Hotswap-1U
 |  | MX42 | MX-NoLED | pcb-rescue:MX-NoLED-MX_Alps_Hybrid | kailh-switches-hotswap:Kailh-Hotswap-1U
 |  | MX43 | MX-NoLED | pcb-rescue:MX-NoLED-MX_Alps_Hybrid | kailh-switches-hotswap:Kailh-Hotswap-1U
 |  | MX44 | MX-NoLED | pcb-rescue:MX-NoLED-MX_Alps_Hybrid | kailh-switches-hotswap:Kailh-Hotswap-1U
 |  | MX45 | MX-NoLED | pcb-rescue:MX-NoLED-MX_Alps_Hybrid | kailh-switches-hotswap:Kailh-Hotswap-1U
 |  | MX46 | MX-NoLED | pcb-rescue:MX-NoLED-MX_Alps_Hybrid | kailh-switches-hotswap:Kailh-Hotswap-1U
 |  | MX47 | MX-NoLED | pcb-rescue:MX-NoLED-MX_Alps_Hybrid | kailh-switches-hotswap:Kailh-Hotswap-1U
 |  | MX48 | MX-NoLED | pcb-rescue:MX-NoLED-MX_Alps_Hybrid | kailh-switches-hotswap:Kailh-Hotswap-1U
 |  | MX49 | MX-NoLED | pcb-rescue:MX-NoLED-MX_Alps_Hybrid | kailh-switches-hotswap:Kailh-Hotswap-1U
 |  | MX50 | MX-NoLED | pcb-rescue:MX-NoLED-MX_Alps_Hybrid | kailh-switches-hotswap:Kailh-Hotswap-1U
 |  | MX51 | MX-NoLED | pcb-rescue:MX-NoLED-MX_Alps_Hybrid | kailh-switches-hotswap:Kailh-Hotswap-1U
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

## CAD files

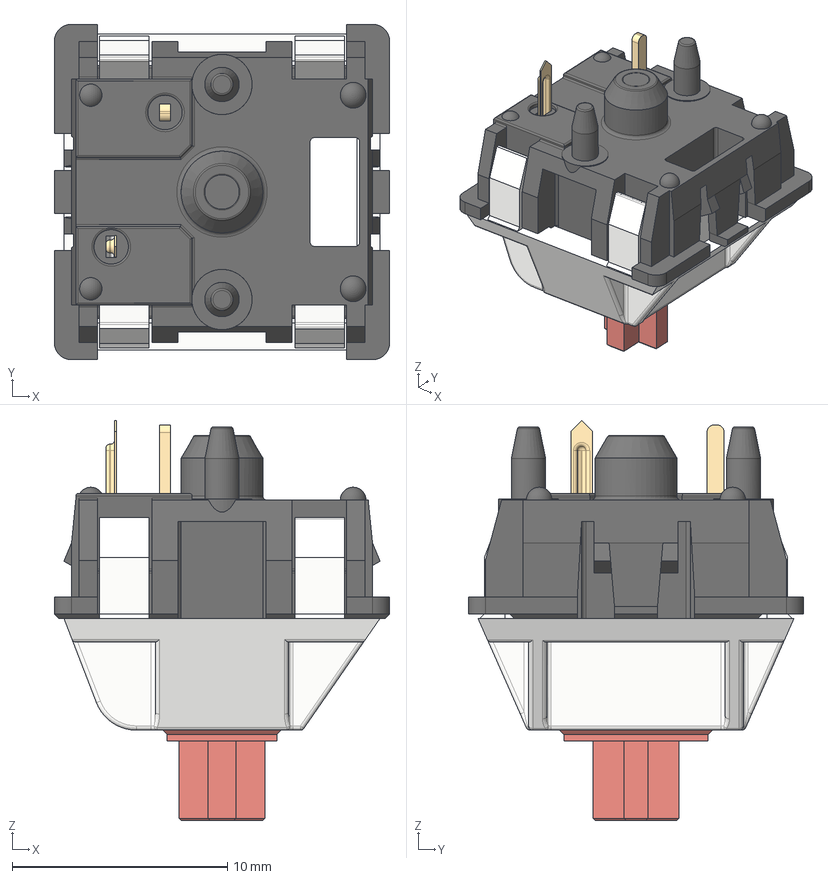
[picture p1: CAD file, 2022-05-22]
Case/3D-parts/asm_mx_asm_PCB v2.step
15.6 x 15.6 x 18.6 mm
MX_DOWN
MX_UP
UP_MX
MX_PIN
MX_SPRING
MX_CLICK

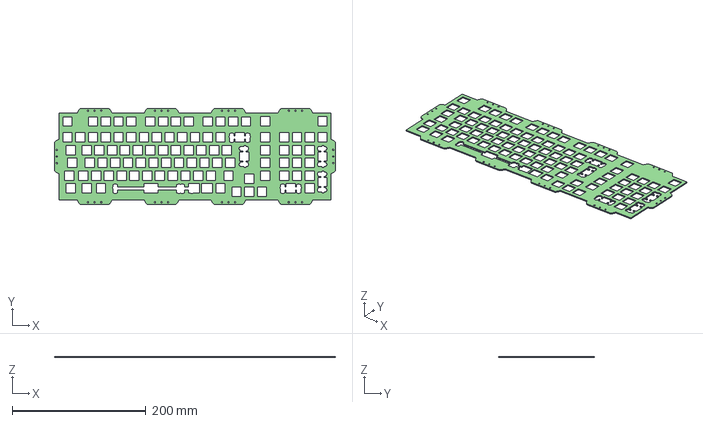
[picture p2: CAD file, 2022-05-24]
Backplate/plate.step
419.8 x 143.8 x 1.60 mm

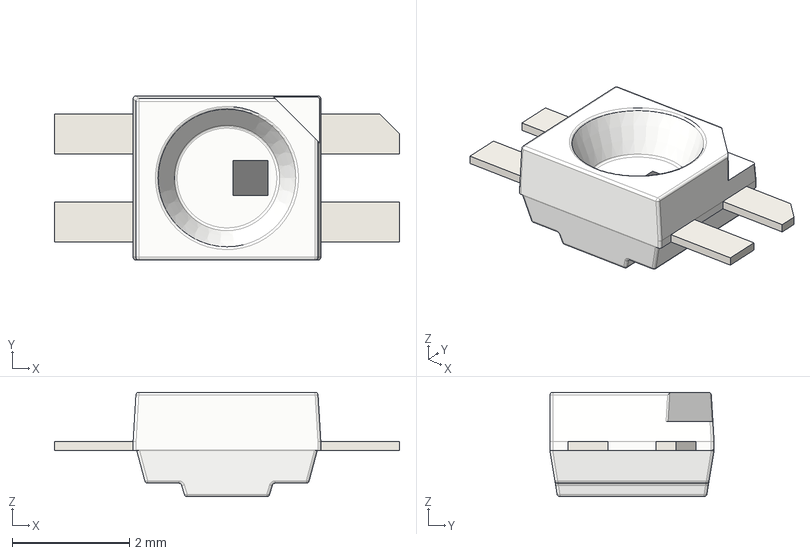
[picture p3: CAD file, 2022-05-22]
Case/3D-parts/LED_SK6812MINI-E v1-mirror.step
5.88 x 2.80 x 1.78 mm

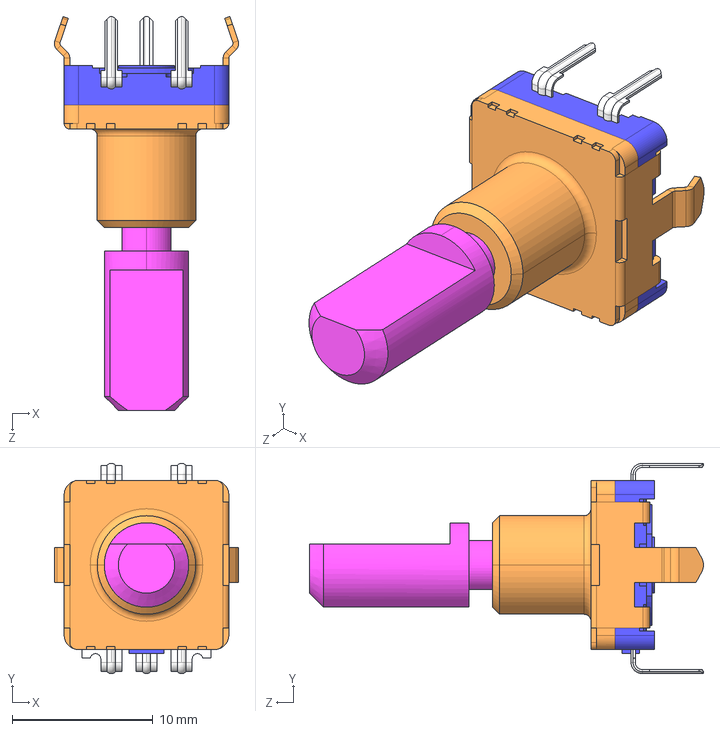
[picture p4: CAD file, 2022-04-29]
PCB/3dPackages/ec11e15244b2/EC11E-15SW.STEP
13.1 x 14.9 x 28.0 mm

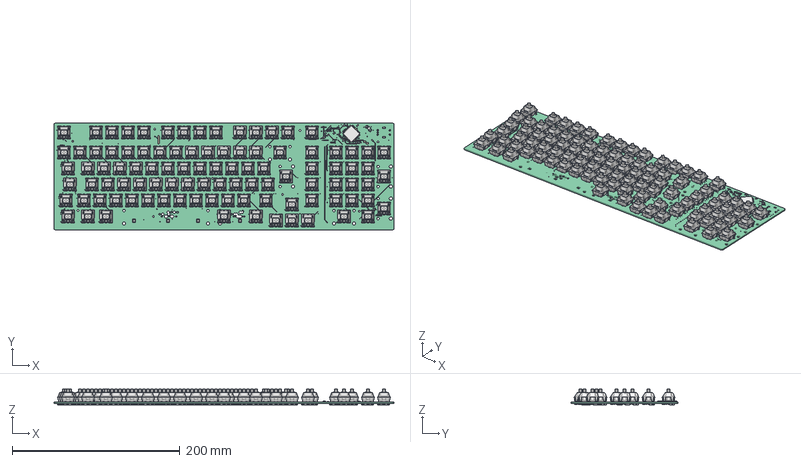
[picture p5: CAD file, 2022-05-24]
Renders/FreeCAD_PCB_withoutFill.FCStd
404.8 x 127.0 x 18.9 mm
Pcb_b19e
topPads_b19e
topTracks_b19e
botPads_b19e
botTracks_b19e
D150_LED_SK6812MINI-E v1_a9155476db2d x 102
MX_DOWN x 98
MX_UP x 98
UP_MX x 98
MX_PIN x 98
MX_SPRING x 98
MX_CLICK x 98
R2_R_0805_2012Metric_de1e642a6a00 x 8
C7_C_0805_2012Metric_bbee324b1ee7 x 109
U1_TQFP_64_14x14mm_P08mm_9c24073d8aa0
Q1_SOT_23_9add4a15e036
Y1_Crystal_SMD_3225-4Pin_3.2x2.5mm_e4a099cf0e58
D31_D_SOD_123_6a4dba0664aa x 101

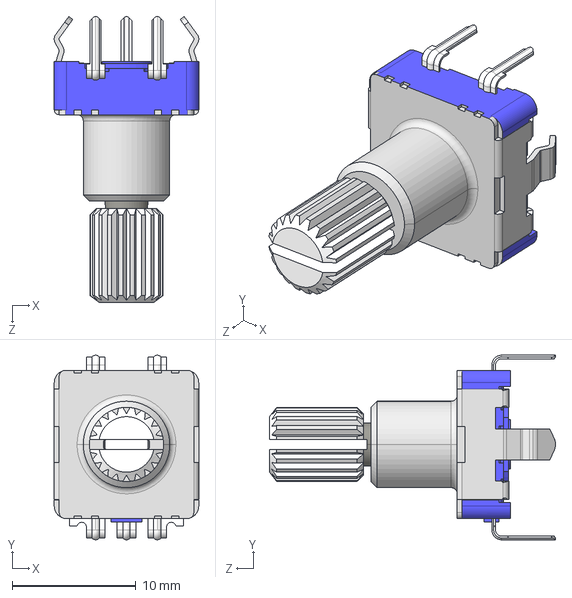
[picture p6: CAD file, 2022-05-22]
Case/3D-parts/EC11 Rotary Encoder Dode Switch-15mm .STEP
11.7 x 15.0 x 23.2 mm

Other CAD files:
Case/3D-parts/asm_mx_asm_PCB.stp
Case/3D-parts/LED_SK6812MINI-E.step
Backplate/plate.dxf
Renders/PCB.blend

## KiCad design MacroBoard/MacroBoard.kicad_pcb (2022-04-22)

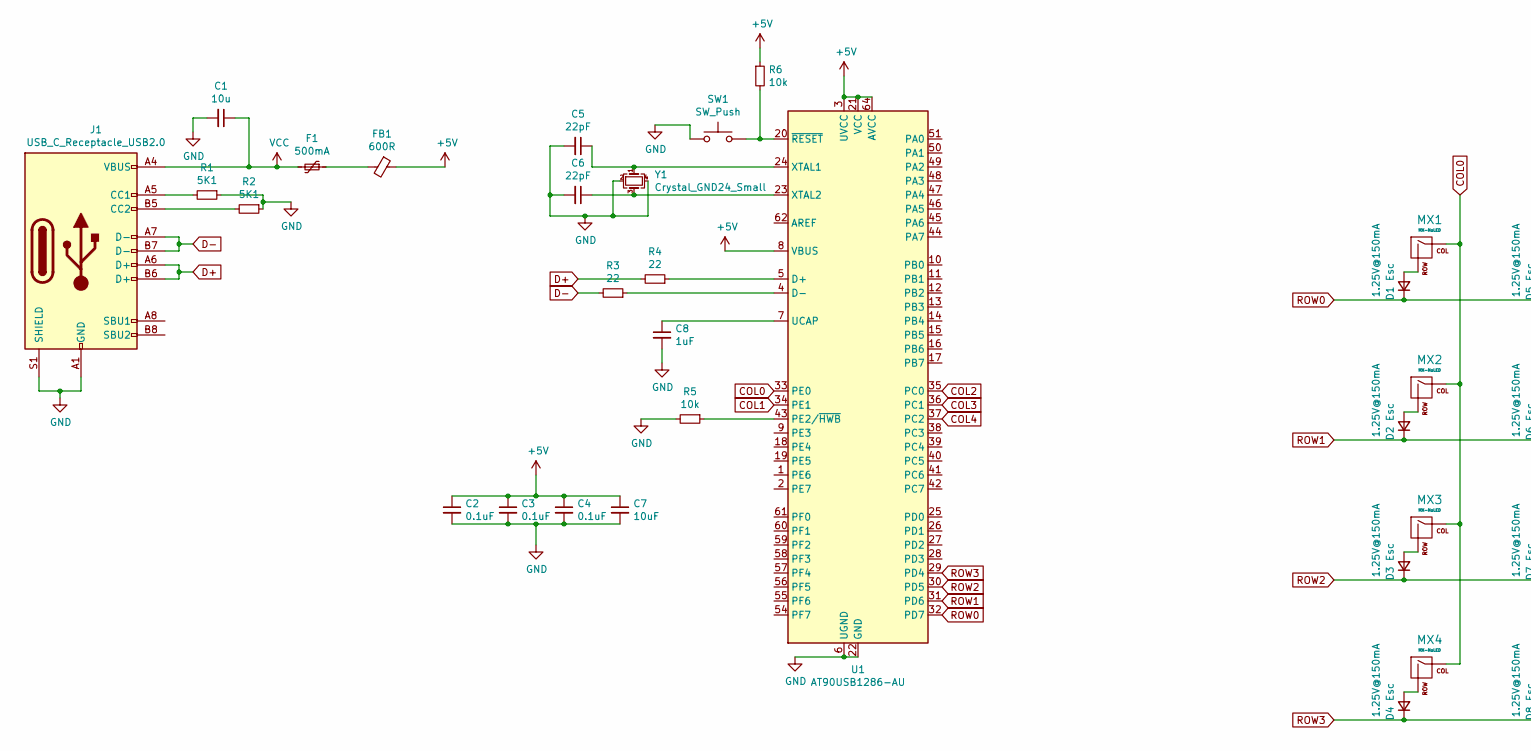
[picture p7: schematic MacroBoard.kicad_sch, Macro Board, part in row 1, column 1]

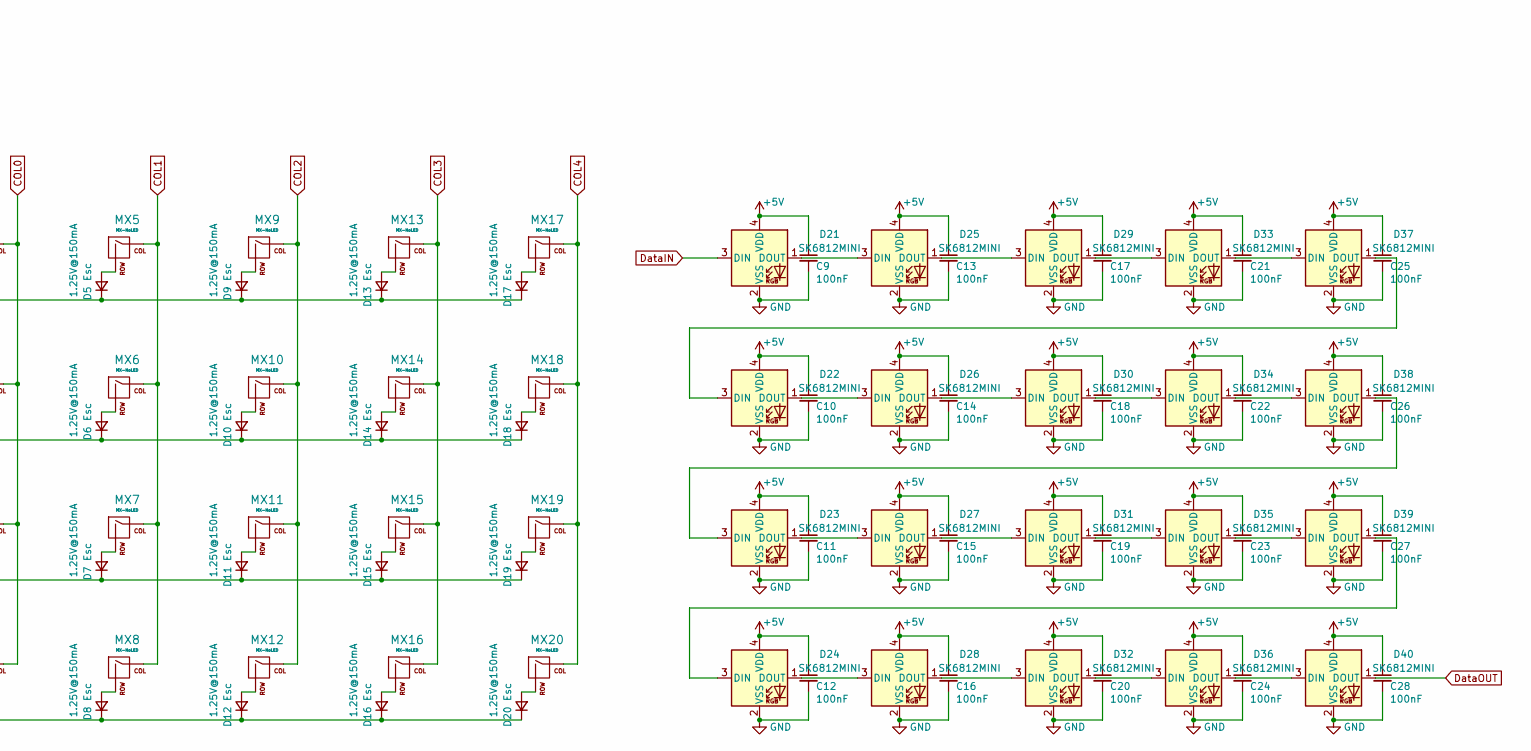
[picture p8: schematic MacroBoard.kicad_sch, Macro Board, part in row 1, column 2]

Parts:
C1: 10u; C_0805_2012Metric
C2, C3, C4: 0.1uF; C_0805_2012Metric
C5, C6: 22pF; C_0805_2012Metric
C7: 10uF; C_0805_2012Metric
C8: 1uF; C_0805_2012Metric
C9, C10, C11, C12, C13, C14, C15, C16, C17, C18, C19, C20, C21, C22, C23, C24, C25, C26, C27, C28: 100nF; led_capacitor
D1, D2, D3, D4, D5, D6, D7, D8, D9, D10, D11, D12, D13, D14, D15, D16, D17, D18, D19, D20: 1.25V@150mA; D_SOD-123
D21, D22, D23, D24, D25, D26, D27, D28, D29, D30, D31, D32, D33, D34, D35, D36, D37, D38, D39, D40: SK6812MINI; SK6812MINI_3.5x3.7mm_SMD-Flipped-Back
F1: 500mA; Fuse_1206_3216Metric
FB1: 600R; Ferrite_Bead_0603
J1: USB_C_Receptacle_USB2.0; USB_C_Receptacle_HRO_TYPE-C-31-M-12
MX1, MX2, MX3, MX4, MX5, MX6, MX7, MX8, MX9, MX10, MX11, MX12, MX13, MX14, MX15, MX16, MX17, MX18, MX19, MX20: MX-NoLED; Kailh-Hotswap-1U
R1, R2: 5K1; R_0805_2012Metric
R3, R4: 22; R_0805_2012Metric
R5, R6: 10k; R_0805_2012Metric
SW1: SW_Push; SKQG-1155865
U1: AT90USB1286-AU; TQFP-64_14x14mm_P0.8mm
Y1: Crystal_GND24_Small; Crystal_SMD_3225-4Pin_3.2x2.5mm

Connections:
+5V: C2.1, C3.1, C4.1, C7.1, C9.1, C10.1, C11.1, C12.1, C13.1, C14.1, C15.1, C16.1, C17.1, C18.1, C19.1, C20.1, C21.1, C22.1, C23.1, C24.1, C25.1, C26.1, C27.1, C28.1, D21.4 (VDD), D22.4 (VDD), D23.4 (VDD), D24.4 (VDD), D25.4 (VDD), D26.4 (VDD), D27.4 (VDD), D28.4 (VDD), D29.4 (VDD), D30.4 (VDD), D31.4 (VDD), D32.4 (VDD), D33.4 (VDD), D34.4 (VDD), D35.4 (VDD), D36.4 (VDD), D37.4 (VDD), D38.4 (VDD), D39.4 (VDD), D40.4 (VDD), FB1.1, R6.1, U1.3 (UVCC), U1.8 (VBUS), U1.21 (VCC), U1.52 (VCC), U1.64 (AVCC)
COL0: MX1.1 (COL), MX2.1 (COL), MX3.1 (COL), MX4.1 (COL), U1.33 (PE0)
COL1: MX5.1 (COL), MX6.1 (COL), MX7.1 (COL), MX8.1 (COL), U1.34 (PE1)
COL2: MX9.1 (COL), MX10.1 (COL), MX11.1 (COL), MX12.1 (COL), U1.35 (PC0)
COL3: MX13.1 (COL), MX14.1 (COL), MX15.1 (COL), MX16.1 (COL), U1.36 (PC1)
COL4: MX17.1 (COL), MX18.1 (COL), MX19.1 (COL), MX20.1 (COL), U1.37 (PC2)
D+: J1.A6 (D+), J1.B6 (D+), R4.2
D-: J1.A7 (D-), J1.B7 (D-), R3.2
DataIN: D21.3 (DIN)
DataOUT: D40.1 (DOUT)
GND: C1.2, C2.2, C3.2, C4.2, C5.2, C6.2, C7.2, C8.2, C9.2, C10.2, C11.2, C12.2, C13.2, C14.2, C15.2, C16.2, C17.2, C18.2, C19.2, C20.2, C21.2, C22.2, C23.2, C24.2, C25.2, C26.2, C27.2, C28.2, D21.2 (VSS), D22.2 (VSS), D23.2 (VSS), D24.2 (VSS), D25.2 (VSS), D26.2 (VSS), D27.2 (VSS), D28.2 (VSS), D29.2 (VSS), D30.2 (VSS), D31.2 (VSS), D32.2 (VSS), D33.2 (VSS), D34.2 (VSS), D35.2 (VSS), D36.2 (VSS), D37.2 (VSS), D38.2 (VSS), D39.2 (VSS), D40.2 (VSS), J1.A1 (GND), J1.A12 (GND), J1.B1 (GND), J1.B12 (GND), J1.S1 (SHIELD), R1.1, R2.1, R5.2, SW1.1, U1.6 (UGND), U1.22 (GND), U1.53 (GND), U1.63 (GND), Y1.2, Y1.4
unnamed: C5.1, U1.24 (XTAL1), Y1.1
unnamed: C6.1, U1.23 (XTAL2), Y1.3
unnamed: C8.1, U1.7 (UCAP)
unnamed: D1.2 (A), MX1.2 (ROW)
unnamed: D2.2 (A), MX2.2 (ROW)
unnamed: D3.2 (A), MX3.2 (ROW)
unnamed: D4.2 (A), MX4.2 (ROW)
unnamed: D5.2 (A), MX5.2 (ROW)
unnamed: D6.2 (A), MX6.2 (ROW)
unnamed: D7.2 (A), MX7.2 (ROW)
unnamed: D8.2 (A), MX8.2 (ROW)
unnamed: D9.2 (A), MX9.2 (ROW)
unnamed: D10.2 (A), MX10.2 (ROW)
unnamed: D11.2 (A), MX11.2 (ROW)
unnamed: D12.2 (A), MX12.2 (ROW)
unnamed: D13.2 (A), MX13.2 (ROW)
unnamed: D14.2 (A), MX14.2 (ROW)
unnamed: D15.2 (A), MX15.2 (ROW)
unnamed: D16.2 (A), MX16.2 (ROW)
unnamed: D17.2 (A), MX17.2 (ROW)
unnamed: D18.2 (A), MX18.2 (ROW)
unnamed: D19.2 (A), MX19.2 (ROW)
unnamed: D20.2 (A), MX20.2 (ROW)
unnamed: D21.1 (DOUT), D25.3 (DIN)
unnamed: D22.1 (DOUT), D26.3 (DIN)
unnamed: D22.3 (DIN), D37.1 (DOUT)
unnamed: D23.1 (DOUT), D27.3 (DIN)
unnamed: D23.3 (DIN), D38.1 (DOUT)
unnamed: D24.1 (DOUT), D28.3 (DIN)
unnamed: D24.3 (DIN), D39.1 (DOUT)
unnamed: D25.1 (DOUT), D29.3 (DIN)
unnamed: D26.1 (DOUT), D30.3 (DIN)
unnamed: D27.1 (DOUT), D31.3 (DIN)
unnamed: D28.1 (DOUT), D32.3 (DIN)
unnamed: D29.1 (DOUT), D33.3 (DIN)
unnamed: D30.1 (DOUT), D34.3 (DIN)
unnamed: D31.1 (DOUT), D35.3 (DIN)
unnamed: D32.1 (DOUT), D36.3 (DIN)
unnamed: D33.1 (DOUT), D37.3 (DIN)
unnamed: D34.1 (DOUT), D38.3 (DIN)
unnamed: D35.1 (DOUT), D39.3 (DIN)
unnamed: D36.1 (DOUT), D40.3 (DIN)
unnamed: F1.1, FB1.2
unnamed: J1.A5 (CC1), R1.2
unnamed: J1.B5 (CC2), R2.2
unnamed: R3.1, U1.4 (D-)
unnamed: R4.1, U1.5 (D+)
unnamed: R5.1, U1.43 (PE2/~HWB)
unnamed: R6.2, SW1.2, U1.20 (~RESET)
ROW0: D1.1 (K), D5.1 (K), D9.1 (K), D13.1 (K), D17.1 (K), U1.32 (PD7)
ROW1: D2.1 (K), D6.1 (K), D10.1 (K), D14.1 (K), D18.1 (K), U1.31 (PD6)
ROW2: D3.1 (K), D7.1 (K), D11.1 (K), D15.1 (K), D19.1 (K), U1.30 (PD5)
ROW3: D4.1 (K), D8.1 (K), D12.1 (K), D16.1 (K), D20.1 (K), U1.29 (PD4)
VCC: C1.1, F1.2, J1.A4 (VBUS), J1.A9 (VBUS), J1.B4 (VBUS), J1.B9 (VBUS)

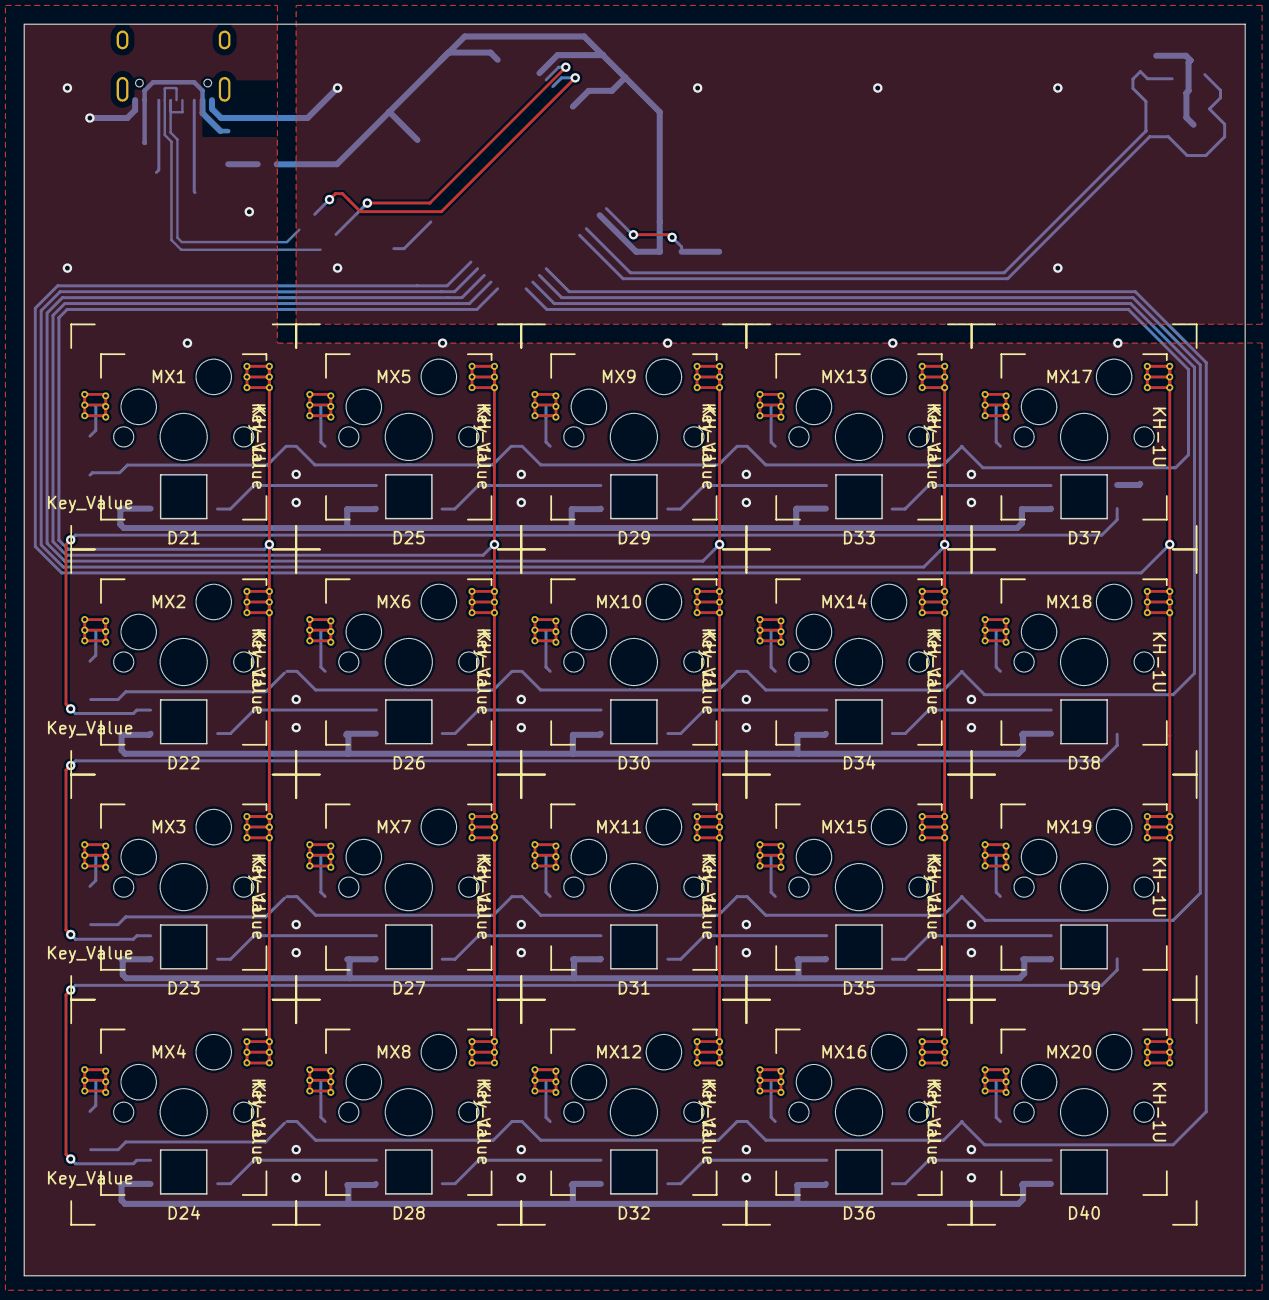
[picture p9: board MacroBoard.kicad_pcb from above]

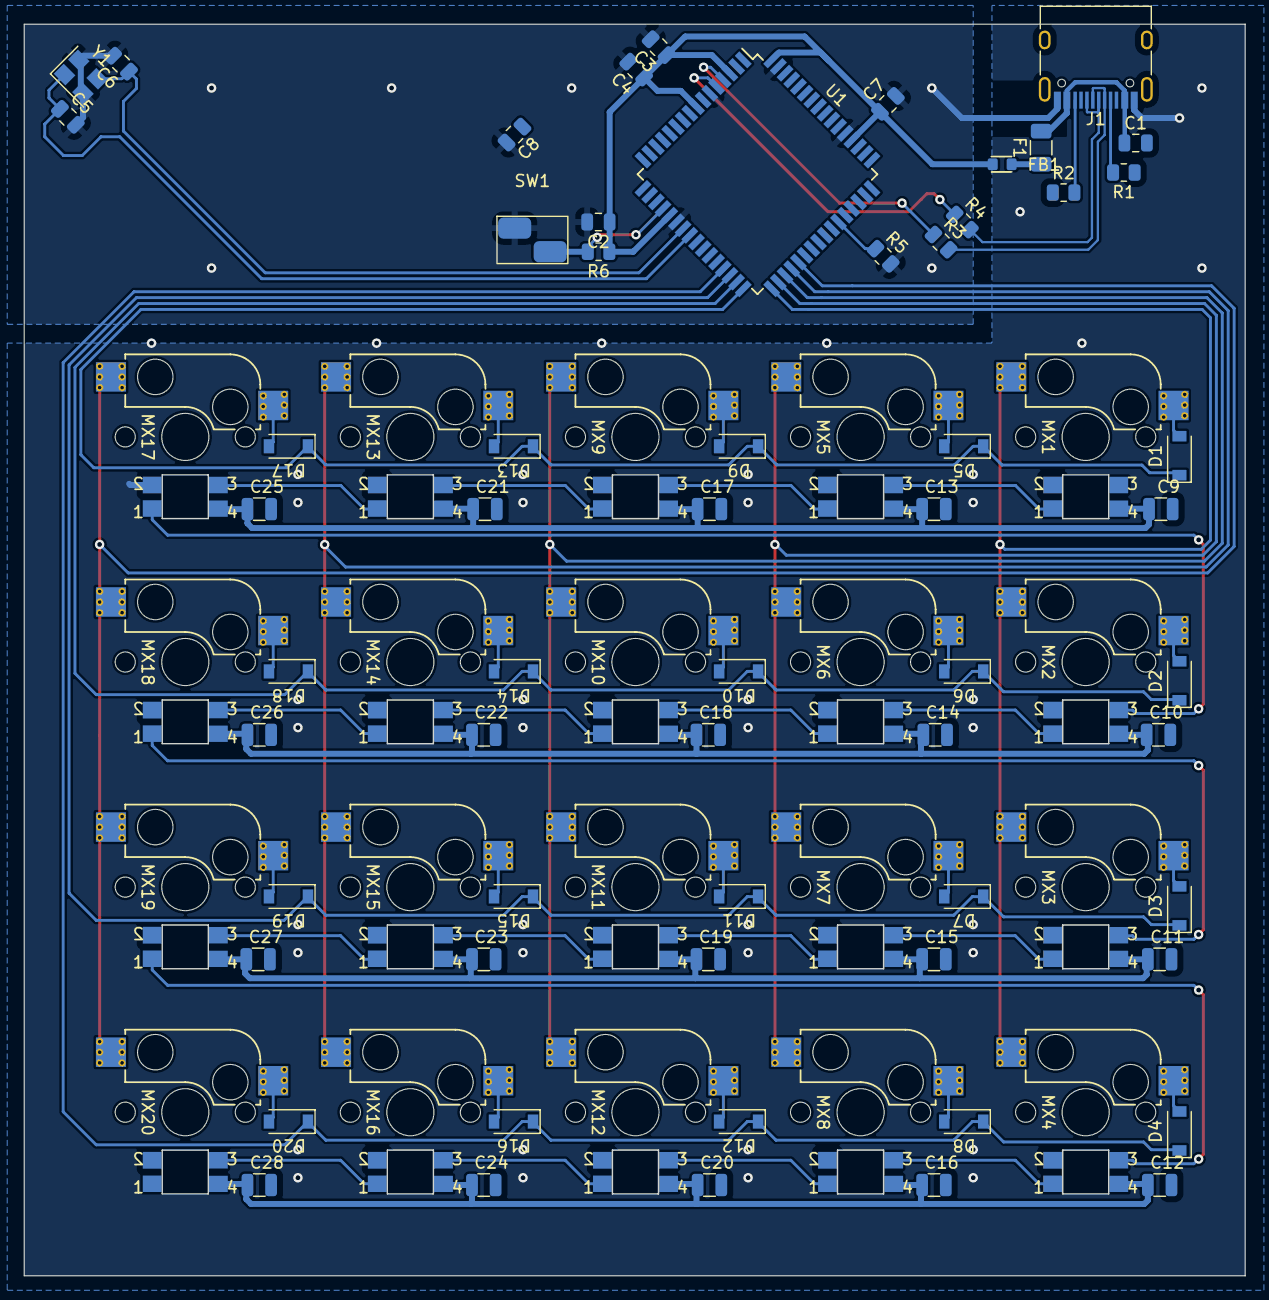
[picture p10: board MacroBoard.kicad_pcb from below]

Board: 2 copper layers, 103.3 x 105.9 mm, 100 parts (60 on the bottom side), 63 nets.

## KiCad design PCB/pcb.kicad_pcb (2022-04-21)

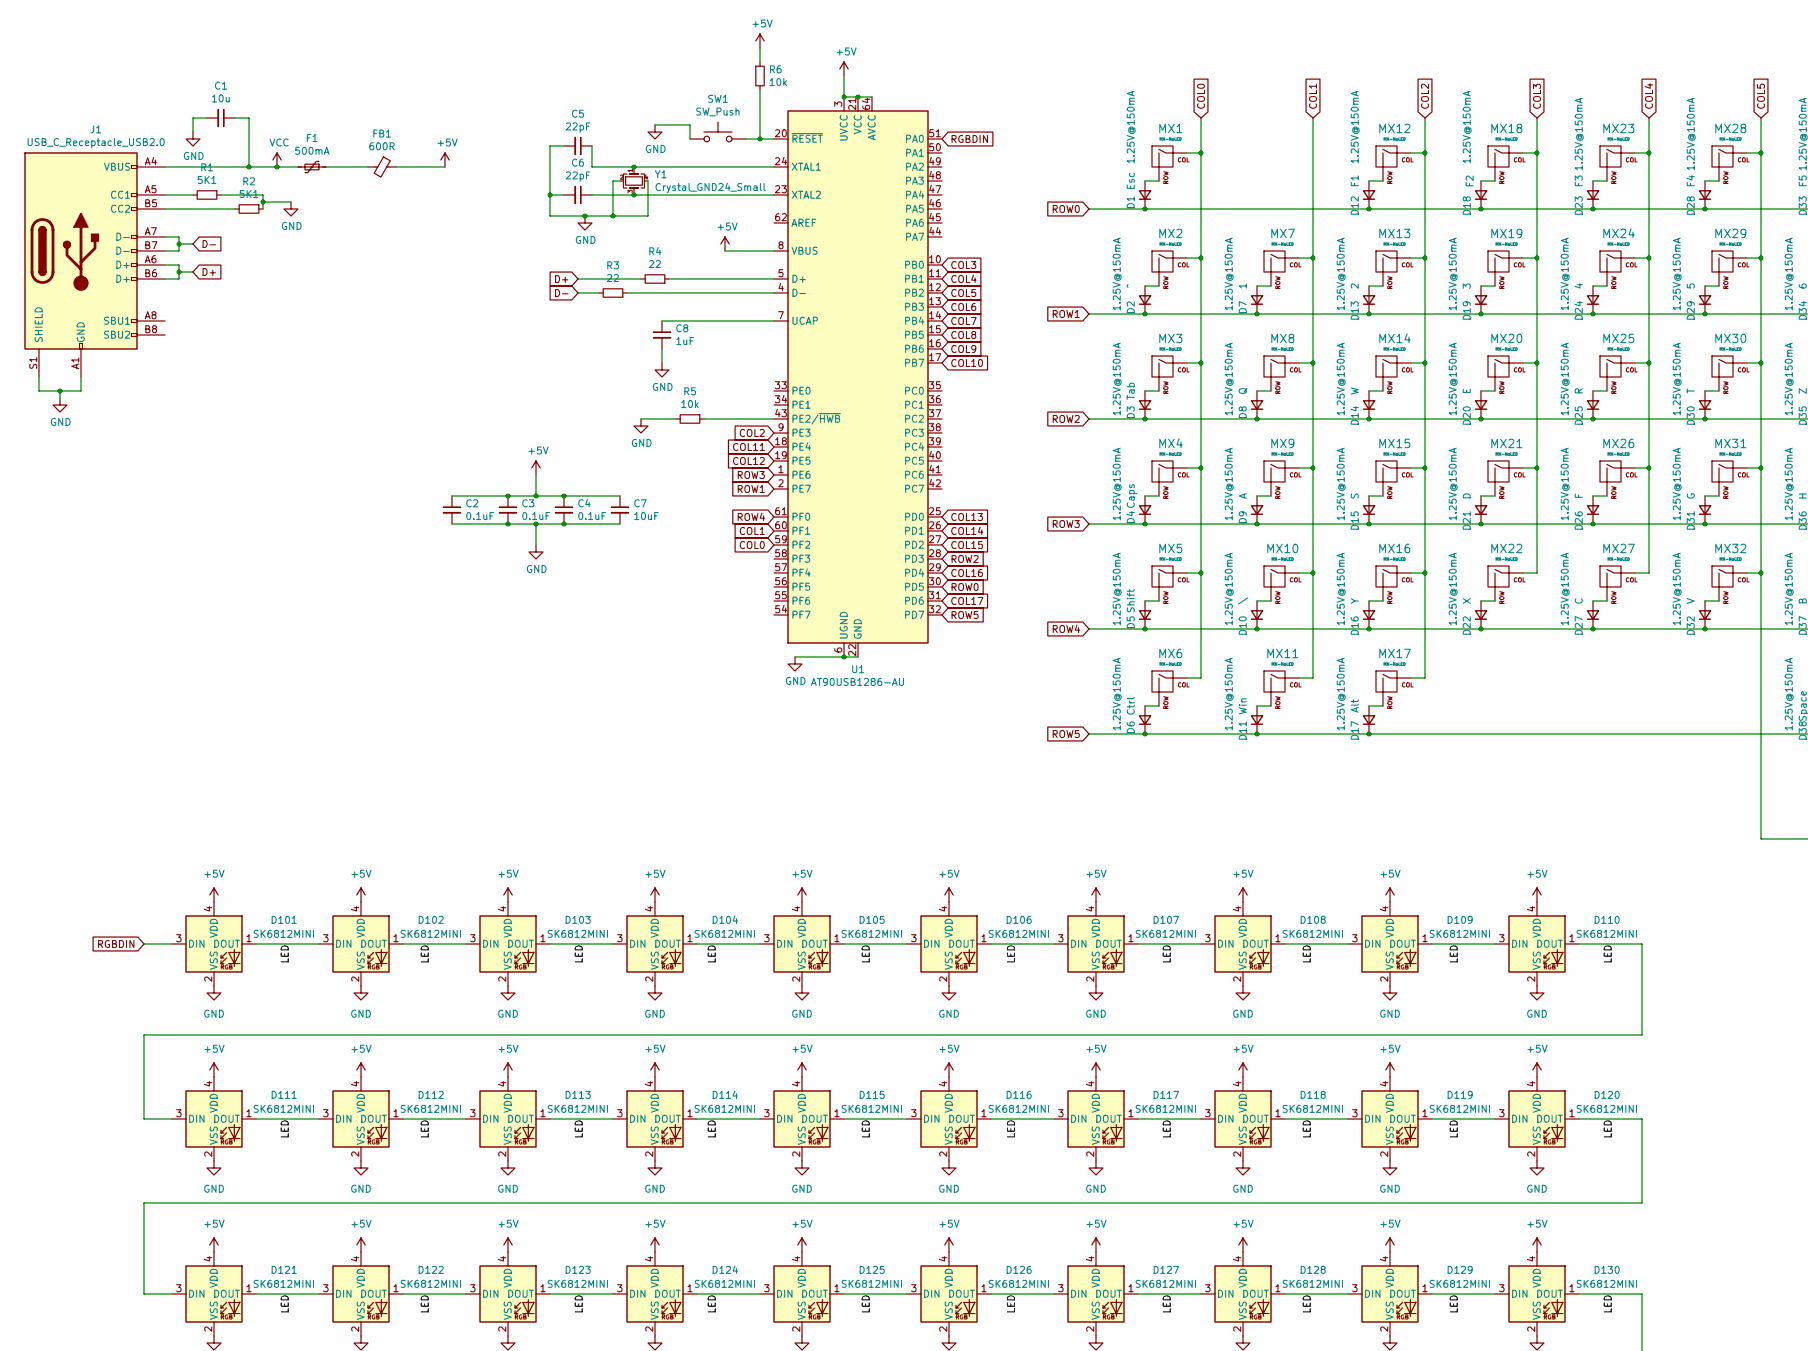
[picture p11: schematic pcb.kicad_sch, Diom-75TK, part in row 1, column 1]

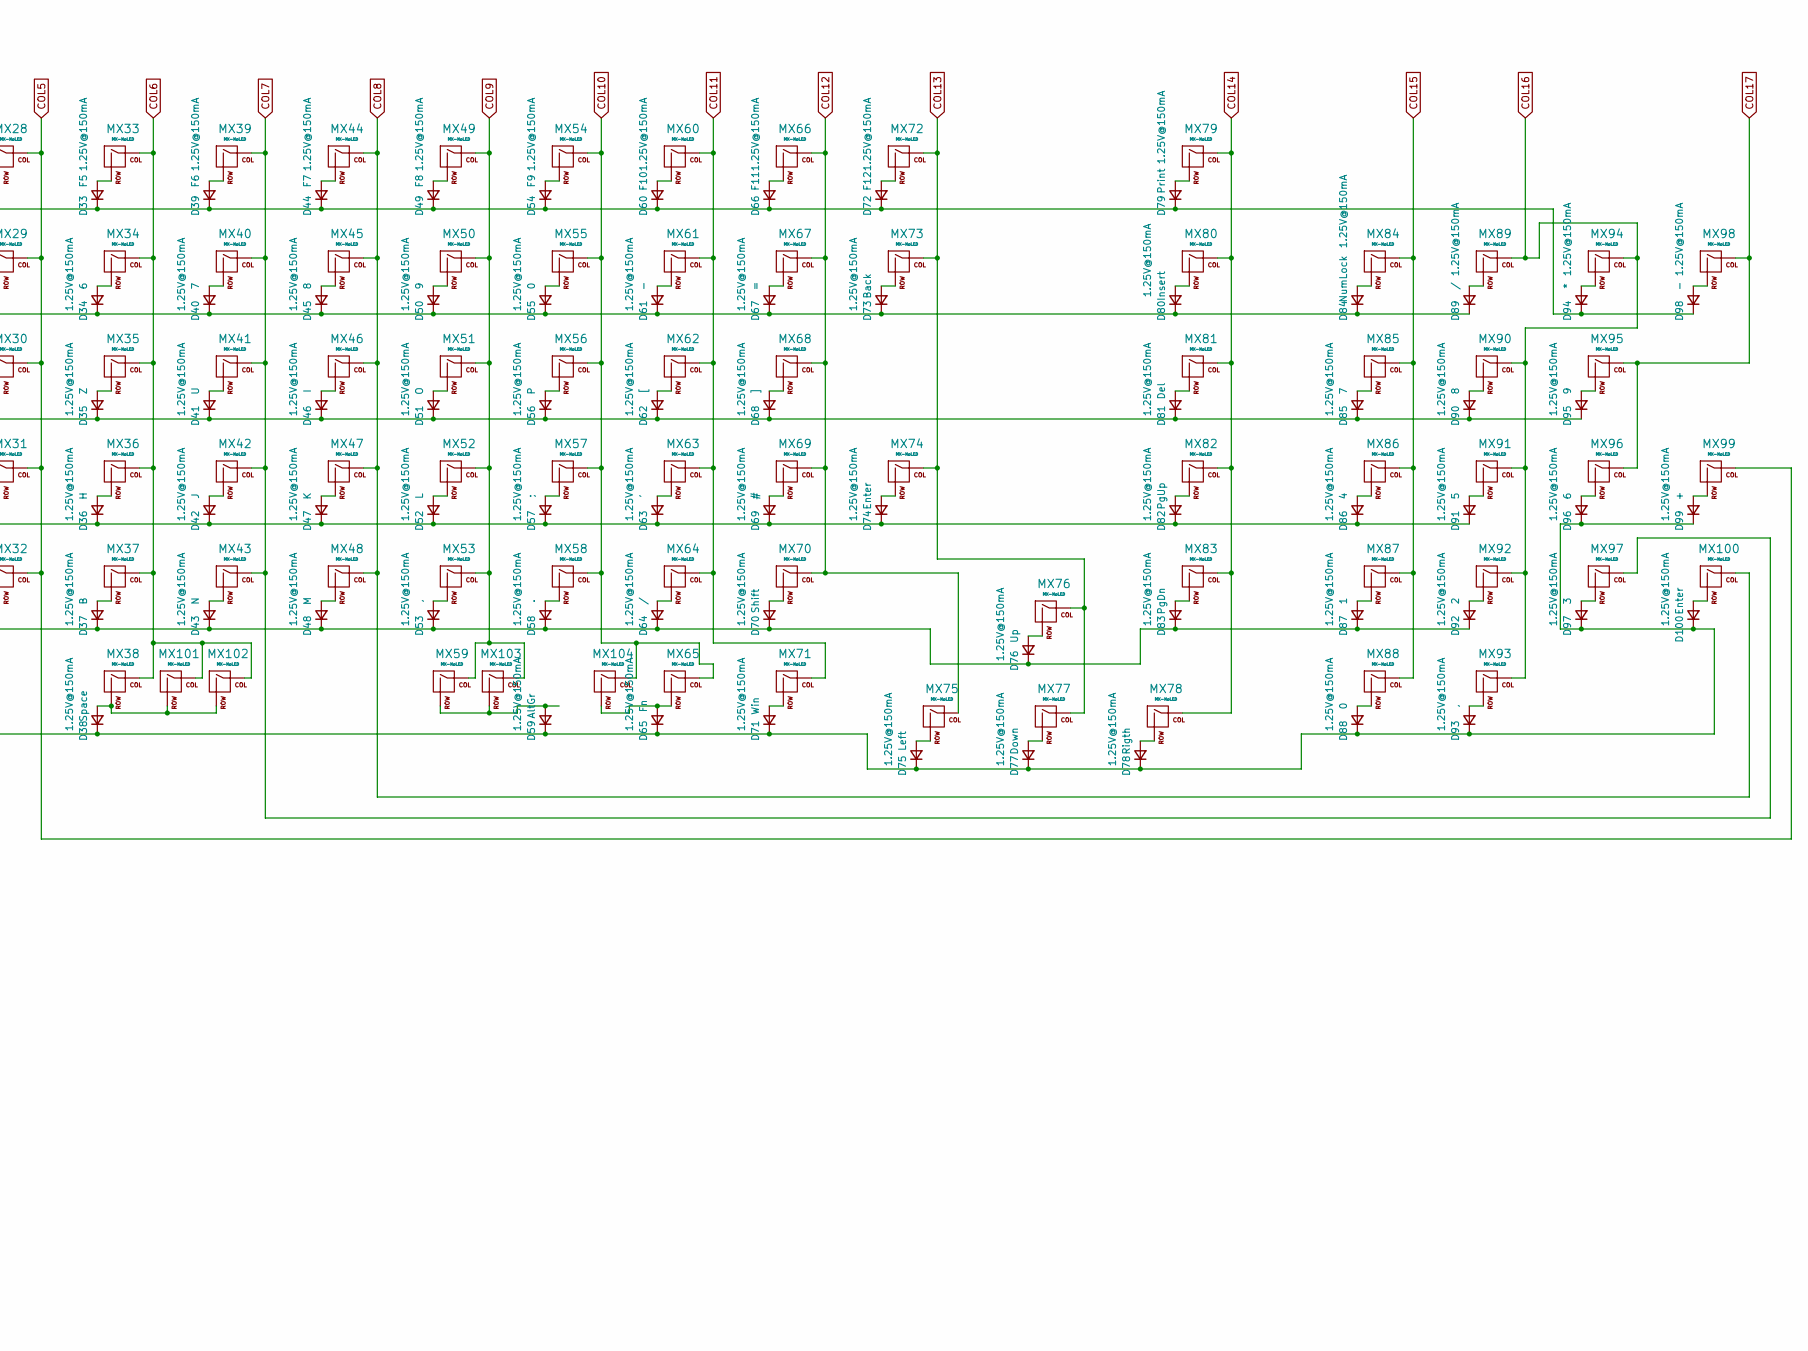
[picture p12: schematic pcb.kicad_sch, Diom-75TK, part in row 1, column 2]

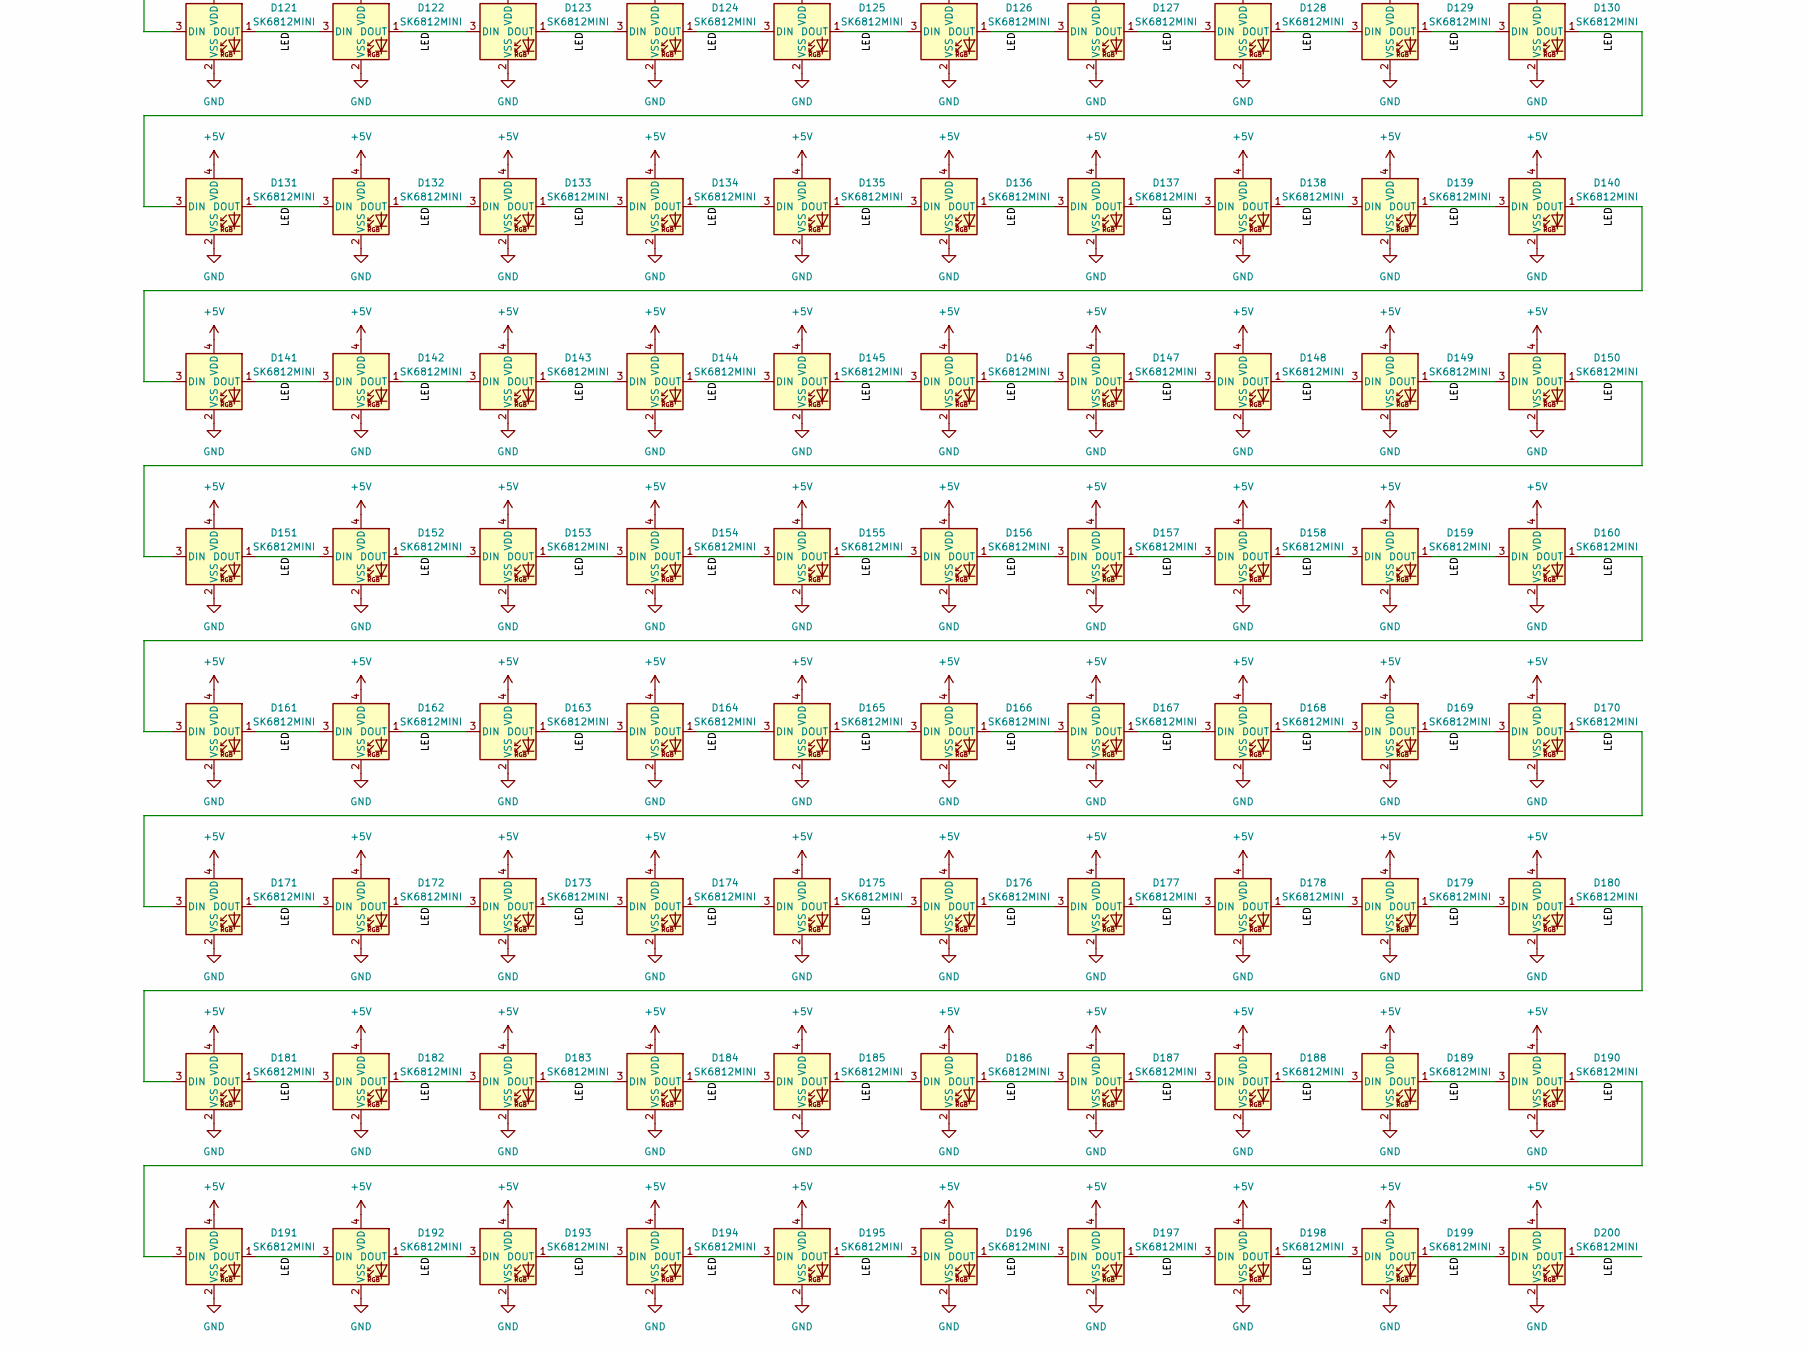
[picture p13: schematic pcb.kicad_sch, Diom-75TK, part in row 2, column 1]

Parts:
C1: 10u; C_0805_2012Metric
C2, C3, C4: 0.1uF; C_0805_2012Metric
C5, C6: 22pF; C_0805_2012Metric
C7: 10uF; C_0805_2012Metric
C8: 1uF; C_0805_2012Metric
D1, D2, D3, D4, D5, D6, D7, D8, D9, D10, D11, D12, D13, D14, D15, D16, D17, D18, D19, D20, D22, D23, D24, D25, D26, D27, D28, D29, D30, D31, D32, D33, D34, D35, D36, D37, D38, D39, D40, D41, D42, D43, D44, D45, D46, D47, D48, D49, D50, D51, D52, D53, D54, D55, D56, D57, D58, D59, D60, D61, D62, D63, D64, D65, D66, D67, D68, D69, D70, D71, D72, D73, D74, D75, D76, D77, D78, D79, D80, D81, D82, D83, D84, D85, D86, D87, D88, D89, D90, D91, D92, D93, D94, D95, D96, D97, D98, D99, D100: 1.25V@150mA; D_SOD-123
D21: 1.25V@150mA
D101, D102, D103, D104, D105, D106, D107, D108, D109, D110, D111, D112, D113, D114, D115, D116, D117, D118, D119, D120, D121, D122, D123, D124, D125, D126, D127, D128, D129, D130, D131, D132, D133, D134, D135, D136, D137, D138, D139, D140, D141, D142, D143, D144, D145, D146, D147, D148, D149, D150, D151, D152, D153, D154, D155, D156, D157, D158, D159, D160, D161, D162, D163, D164, D165, D166, D167, D168, D169, D170, D171, D172, D173, D174, D175, D176, D177, D178, D179, D180, D181, D182, D183, D184, D185, D186, D187, D188, D189, D190, D191, D192, D193, D194, D195, D196, D197, D198, D199, D200: SK6812MINI; SK6812MINI_3.5x3.7mm_SMD-Flipped-Back
F1: 500mA; Fuse_1206_3216Metric
FB1: 600R; Ferrite_Bead_0603
J1: USB_C_Receptacle_USB2.0; USB_C_Receptacle_HRO_TYPE-C-31-M-12
MX1, MX2, MX7, MX8, MX9, MX10, MX11, MX12, MX13, MX14, MX15, MX16, MX18, MX19, MX20, MX21, MX22, MX23, MX24, MX25, MX26, MX27, MX28, MX29, MX30, MX31, MX32, MX33, MX34, MX35, MX36, MX37, MX39, MX40, MX41, MX42, MX43, MX44, MX45, MX46, MX47, MX48, MX49, MX50, MX51, MX52, MX53, MX54, MX55, MX56, MX57, MX58, MX60, MX61, MX62, MX63, MX64, MX65, MX66, MX67, MX68, MX69, MX71, MX72, MX75, MX76, MX77, MX78, MX79, MX80, MX81, MX82, MX83, MX84, MX85, MX86, MX87, MX89, MX90, MX91, MX92, MX93, MX94, MX95, MX96, MX97, MX98, MX103: MX-NoLED; Kailh-Hotswap-1U
MX3, MX6: MX-NoLED; Kailh-Hotswap-1.5U
MX4, MX70: MX-NoLED; Kailh-Hotswap-1.75U
MX5, MX17, MX59, MX104: MX-NoLED; Kailh-Hotswap-1.25U
MX38: MX-NoLED; Kailh-Hotswap-6U
MX73, MX88: MX-NoLED; Kailh-Hotswap-2U
MX74: MX-NoLED; Kailh-Hotswap-EnterISO
MX99, MX100: MX-NoLED; Kailh-Hotswap-2U-Vertical
MX101: MX-NoLED; Kailh-Hotswap-6.25U
MX102: MX-NoLED; Kailh-Hotswap-7U
R1, R2: 5K1; R_0805_2012Metric
R3, R4: 22; R_0805_2012Metric
R5, R6: 10k; R_0805_2012Metric
SW1: SW_Push
U1: AT90USB1286-AU; TQFP-64_14x14mm_P0.8mm
Y1: Crystal_GND24_Small; Crystal_SMD_3225-4Pin_3.2x2.5mm

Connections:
+5V: C2.1, C3.1, C4.1, C7.1, D101.4 (VDD), D102.4 (VDD), D103.4 (VDD), D104.4 (VDD), D105.4 (VDD), D106.4 (VDD), D107.4 (VDD), D108.4 (VDD), D109.4 (VDD), D110.4 (VDD), D111.4 (VDD), D112.4 (VDD), D113.4 (VDD), D114.4 (VDD), D115.4 (VDD), D116.4 (VDD), D117.4 (VDD), D118.4 (VDD), D119.4 (VDD), D120.4 (VDD), D121.4 (VDD), D122.4 (VDD), D123.4 (VDD), D124.4 (VDD), D125.4 (VDD), D126.4 (VDD), D127.4 (VDD), D128.4 (VDD), D129.4 (VDD), D130.4 (VDD), D131.4 (VDD), D132.4 (VDD), D133.4 (VDD), D134.4 (VDD), D135.4 (VDD), D136.4 (VDD), D137.4 (VDD), D138.4 (VDD), D139.4 (VDD), D140.4 (VDD), D141.4 (VDD), D142.4 (VDD), D143.4 (VDD), D144.4 (VDD), D145.4 (VDD), D146.4 (VDD), D147.4 (VDD), D148.4 (VDD), D149.4 (VDD), D150.4 (VDD), D151.4 (VDD), D152.4 (VDD), D153.4 (VDD), D154.4 (VDD), D155.4 (VDD), D156.4 (VDD), D157.4 (VDD), D158.4 (VDD), D159.4 (VDD), D160.4 (VDD), D161.4 (VDD), D162.4 (VDD), D163.4 (VDD), D164.4 (VDD), D165.4 (VDD), D166.4 (VDD), D167.4 (VDD), D168.4 (VDD), D169.4 (VDD), D170.4 (VDD), D171.4 (VDD), D172.4 (VDD), D173.4 (VDD), D174.4 (VDD), D175.4 (VDD), D176.4 (VDD), D177.4 (VDD), D178.4 (VDD), D179.4 (VDD), D180.4 (VDD), D181.4 (VDD), D182.4 (VDD), D183.4 (VDD), D184.4 (VDD), D185.4 (VDD), D186.4 (VDD), D187.4 (VDD), D188.4 (VDD), D189.4 (VDD), D190.4 (VDD), D191.4 (VDD), D192.4 (VDD), D193.4 (VDD), D194.4 (VDD), D195.4 (VDD), D196.4 (VDD), D197.4 (VDD), D198.4 (VDD), D199.4 (VDD), D200.4 (VDD), FB1.1, R6.1, U1.3 (UVCC), U1.8 (VBUS), U1.21 (VCC), U1.52 (VCC), U1.64 (AVCC)
/LED: D101.1 (DOUT), D102.1 (DOUT), D102.3 (DIN), D103.1 (DOUT), D103.3 (DIN), D104.1 (DOUT), D104.3 (DIN), D105.1 (DOUT), D105.3 (DIN), D106.1 (DOUT), D106.3 (DIN), D107.1 (DOUT), D107.3 (DIN), D108.1 (DOUT), D108.3 (DIN), D109.1 (DOUT), D109.3 (DIN), D110.1 (DOUT), D110.3 (DIN), D111.1 (DOUT), D111.3 (DIN), D112.1 (DOUT), D112.3 (DIN), D113.1 (DOUT), D113.3 (DIN), D114.1 (DOUT), D114.3 (DIN), D115.1 (DOUT), D115.3 (DIN), D116.1 (DOUT), D116.3 (DIN), D117.1 (DOUT), D117.3 (DIN), D118.1 (DOUT), D118.3 (DIN), D119.1 (DOUT), D119.3 (DIN), D120.1 (DOUT), D120.3 (DIN), D121.1 (DOUT), D121.3 (DIN), D122.1 (DOUT), D122.3 (DIN), D123.1 (DOUT), D123.3 (DIN), D124.1 (DOUT), D124.3 (DIN), D125.1 (DOUT), D125.3 (DIN), D126.1 (DOUT), D126.3 (DIN), D127.1 (DOUT), D127.3 (DIN), D128.1 (DOUT), D128.3 (DIN), D129.1 (DOUT), D129.3 (DIN), D130.1 (DOUT), D130.3 (DIN), D131.1 (DOUT), D131.3 (DIN), D132.1 (DOUT), D132.3 (DIN), D133.1 (DOUT), D133.3 (DIN), D134.1 (DOUT), D134.3 (DIN), D135.1 (DOUT), D135.3 (DIN), D136.1 (DOUT), D136.3 (DIN), D137.1 (DOUT), D137.3 (DIN), D138.1 (DOUT), D138.3 (DIN), D139.1 (DOUT), D139.3 (DIN), D140.1 (DOUT), D140.3 (DIN), D141.1 (DOUT), D141.3 (DIN), D142.1 (DOUT), D142.3 (DIN), D143.1 (DOUT), D143.3 (DIN), D144.1 (DOUT), D144.3 (DIN), D145.1 (DOUT), D145.3 (DIN), D146.1 (DOUT), D146.3 (DIN), D147.1 (DOUT), D147.3 (DIN), D148.1 (DOUT), D148.3 (DIN), D149.1 (DOUT), D149.3 (DIN), D150.1 (DOUT), D150.3 (DIN), D151.1 (DOUT), D151.3 (DIN), D152.1 (DOUT), D152.3 (DIN), D153.1 (DOUT), D153.3 (DIN), D154.1 (DOUT), D154.3 (DIN), D155.1 (DOUT), D155.3 (DIN), D156.1 (DOUT), D156.3 (DIN), D157.1 (DOUT), D157.3 (DIN), D158.1 (DOUT), D158.3 (DIN), D159.1 (DOUT), D159.3 (DIN), D160.1 (DOUT), D160.3 (DIN), D161.1 (DOUT), D161.3 (DIN), D162.1 (DOUT), D162.3 (DIN), D163.1 (DOUT), D163.3 (DIN), D164.1 (DOUT), D164.3 (DIN), D165.1 (DOUT), D165.3 (DIN), D166.1 (DOUT), D166.3 (DIN), D167.1 (DOUT), D167.3 (DIN), D168.1 (DOUT), D168.3 (DIN), D169.1 (DOUT), D169.3 (DIN), D170.1 (DOUT), D170.3 (DIN), D171.1 (DOUT), D171.3 (DIN), D172.1 (DOUT), D172.3 (DIN), D173.1 (DOUT), D173.3 (DIN), D174.1 (DOUT), D174.3 (DIN), D175.1 (DOUT), D175.3 (DIN), D176.1 (DOUT), D176.3 (DIN), D177.1 (DOUT), D177.3 (DIN), D178.1 (DOUT), D178.3 (DIN), D179.1 (DOUT), D179.3 (DIN), D180.1 (DOUT), D180.3 (DIN), D181.1 (DOUT), D181.3 (DIN), D182.1 (DOUT), D182.3 (DIN), D183.1 (DOUT), D183.3 (DIN), D184.1 (DOUT), D184.3 (DIN), D185.1 (DOUT), D185.3 (DIN), D186.1 (DOUT), D186.3 (DIN), D187.1 (DOUT), D187.3 (DIN), D188.1 (DOUT), D188.3 (DIN), D189.1 (DOUT), D189.3 (DIN), D190.1 (DOUT), D190.3 (DIN), D191.1 (DOUT), D191.3 (DIN), D192.1 (DOUT), D192.3 (DIN), D193.1 (DOUT), D193.3 (DIN), D194.1 (DOUT), D194.3 (DIN), D195.1 (DOUT), D195.3 (DIN), D196.1 (DOUT), D196.3 (DIN), D197.1 (DOUT), D197.3 (DIN), D198.1 (DOUT), D198.3 (DIN), D199.1 (DOUT), D199.3 (DIN), D200.1 (DOUT), D200.3 (DIN)
COL0: MX1.1 (COL), MX2.1 (COL), MX3.1 (COL), MX4.1 (COL), MX5.1 (COL), MX6.1 (COL), U1.59 (PF2)
COL1: MX7.1 (COL), MX8.1 (COL), MX9.1 (COL), MX10.1 (COL), MX11.1 (COL), U1.60 (PF1)
COL2: MX12.1 (COL), MX13.1 (COL), MX14.1 (COL), MX15.1 (COL), MX16.1 (COL), MX17.1 (COL), U1.9 (PE3)
COL3: MX18.1 (COL), MX19.1 (COL), MX20.1 (COL), MX21.1 (COL), MX22.1 (COL), U1.10 (PB0)
COL4: MX23.1 (COL), MX24.1 (COL), MX25.1 (COL), MX26.1 (COL), MX27.1 (COL), U1.11 (PB1)
COL5: MX28.1 (COL), MX29.1 (COL), MX30.1 (COL), MX31.1 (COL), MX32.1 (COL), MX99.1 (COL), U1.12 (PB2)
COL6: MX33.1 (COL), MX34.1 (COL), MX35.1 (COL), MX36.1 (COL), MX37.1 (COL), MX38.1 (COL), MX101.1 (COL), MX102.1 (COL), U1.13 (PB3)
COL7: MX39.1 (COL), MX40.1 (COL), MX41.1 (COL), MX42.1 (COL), MX43.1 (COL), MX97.1 (COL), U1.14 (PB4)
COL8: MX44.1 (COL), MX45.1 (COL), MX46.1 (COL), MX47.1 (COL), MX48.1 (COL), MX100.1 (COL), U1.15 (PB5)
COL9: MX49.1 (COL), MX50.1 (COL), MX51.1 (COL), MX52.1 (COL), MX53.1 (COL), MX59.1 (COL), MX103.1 (COL), U1.16 (PB6)
COL10: MX54.1 (COL), MX55.1 (COL), MX56.1 (COL), MX57.1 (COL), MX58.1 (COL), MX65.1 (COL), MX104.1 (COL), U1.17 (PB7)
COL11: MX60.1 (COL), MX61.1 (COL), MX62.1 (COL), MX63.1 (COL), MX64.1 (COL), MX71.1 (COL), U1.18 (PE4)
COL12: MX66.1 (COL), MX67.1 (COL), MX68.1 (COL), MX69.1 (COL), MX70.1 (COL), MX75.1 (COL), U1.19 (PE5)
COL13: MX72.1 (COL), MX73.1 (COL), MX74.1 (COL), MX76.1 (COL), MX77.1 (COL), U1.25 (PD0)
COL14: MX78.1 (COL), MX79.1 (COL), MX80.1 (COL), MX81.1 (COL), MX82.1 (COL), MX83.1 (COL), U1.26 (PD1)
COL15: MX84.1 (COL), MX85.1 (COL), MX86.1 (COL), MX87.1 (COL), MX88.1 (COL), U1.27 (PD2)
COL16: MX89.1 (COL), MX90.1 (COL), MX91.1 (COL), MX92.1 (COL), MX93.1 (COL), MX94.1 (COL), U1.29 (PD4)
COL17: MX95.1 (COL), MX96.1 (COL), MX98.1 (COL), U1.31 (PD6)
D+: J1.A6 (D+), J1.B6 (D+), R4.2
D-: J1.A7 (D-), J1.B7 (D-), R3.2
GND: C1.2, C2.2, C3.2, C4.2, C5.2, C6.2, C7.2, C8.2, D101.2 (VSS), D102.2 (VSS), D103.2 (VSS), D104.2 (VSS), D105.2 (VSS), D106.2 (VSS), D107.2 (VSS), D108.2 (VSS), D109.2 (VSS), D110.2 (VSS), D111.2 (VSS), D112.2 (VSS), D113.2 (VSS), D114.2 (VSS), D115.2 (VSS), D116.2 (VSS), D117.2 (VSS), D118.2 (VSS), D119.2 (VSS), D120.2 (VSS), D121.2 (VSS), D122.2 (VSS), D123.2 (VSS), D124.2 (VSS), D125.2 (VSS), D126.2 (VSS), D127.2 (VSS), D128.2 (VSS), D129.2 (VSS), D130.2 (VSS), D131.2 (VSS), D132.2 (VSS), D133.2 (VSS), D134.2 (VSS), D135.2 (VSS), D136.2 (VSS), D137.2 (VSS), D138.2 (VSS), D139.2 (VSS), D140.2 (VSS), D141.2 (VSS), D142.2 (VSS), D143.2 (VSS), D144.2 (VSS), D145.2 (VSS), D146.2 (VSS), D147.2 (VSS), D148.2 (VSS), D149.2 (VSS), D150.2 (VSS), D151.2 (VSS), D152.2 (VSS), D153.2 (VSS), D154.2 (VSS), D155.2 (VSS), D156.2 (VSS), D157.2 (VSS), D158.2 (VSS), D159.2 (VSS), D160.2 (VSS), D161.2 (VSS), D162.2 (VSS), D163.2 (VSS), D164.2 (VSS), D165.2 (VSS), D166.2 (VSS), D167.2 (VSS), D168.2 (VSS), D169.2 (VSS), D170.2 (VSS), D171.2 (VSS), D172.2 (VSS), D173.2 (VSS), D174.2 (VSS), D175.2 (VSS), D176.2 (VSS), D177.2 (VSS), D178.2 (VSS), D179.2 (VSS), D180.2 (VSS), D181.2 (VSS), D182.2 (VSS), D183.2 (VSS), D184.2 (VSS), D185.2 (VSS), D186.2 (VSS), D187.2 (VSS), D188.2 (VSS), D189.2 (VSS), D190.2 (VSS), D191.2 (VSS), D192.2 (VSS), D193.2 (VSS), D194.2 (VSS), D195.2 (VSS), D196.2 (VSS), D197.2 (VSS), D198.2 (VSS), D199.2 (VSS), D200.2 (VSS), J1.A1 (GND), J1.A12 (GND), J1.B1 (GND), J1.B12 (GND), J1.S1 (SHIELD), R1.1, R2.1, R5.2, SW1.1, U1.6 (UGND), U1.22 (GND), U1.53 (GND), U1.63 (GND), Y1.2, Y1.4
unnamed: C5.1, U1.24 (XTAL1), Y1.1
unnamed: C6.1, U1.23 (XTAL2), Y1.3
unnamed: C8.1, U1.7 (UCAP)
unnamed: D1.2 (A), MX1.2 (ROW)
unnamed: D2.2 (A), MX2.2 (ROW)
unnamed: D3.2 (A), MX3.2 (ROW)
unnamed: D4.2 (A), MX4.2 (ROW)
unnamed: D5.2 (A), MX5.2 (ROW)
unnamed: D6.2 (A), MX6.2 (ROW)
unnamed: D7.2 (A), MX7.2 (ROW)
unnamed: D8.2 (A), MX8.2 (ROW)
unnamed: D9.2 (A), MX9.2 (ROW)
unnamed: D10.2 (A), MX10.2 (ROW)
unnamed: D11.2 (A), MX11.2 (ROW)
unnamed: D12.2 (A), MX12.2 (ROW)
unnamed: D13.2 (A), MX13.2 (ROW)
unnamed: D14.2 (A), MX14.2 (ROW)
unnamed: D15.2 (A), MX15.2 (ROW)
unnamed: D16.2 (A), MX16.2 (ROW)
unnamed: D17.2 (A), MX17.2 (ROW)
unnamed: D18.2 (A), MX18.2 (ROW)
unnamed: D19.2 (A), MX19.2 (ROW)
unnamed: D20.2 (A), MX20.2 (ROW)
unnamed: D21.2 (A), MX21.2 (ROW)
unnamed: D22.2 (A), MX22.2 (ROW)
unnamed: D23.2 (A), MX23.2 (ROW)
unnamed: D24.2 (A), MX24.2 (ROW)
unnamed: D25.2 (A), MX25.2 (ROW)
unnamed: D26.2 (A), MX26.2 (ROW)
unnamed: D27.2 (A), MX27.2 (ROW)
unnamed: D28.2 (A), MX28.2 (ROW)
unnamed: D29.2 (A), MX29.2 (ROW)
unnamed: D30.2 (A), MX30.2 (ROW)
unnamed: D31.2 (A), MX31.2 (ROW)
unnamed: D32.2 (A), MX32.2 (ROW)
unnamed: D33.2 (A), MX33.2 (ROW)
unnamed: D34.2 (A), MX34.2 (ROW)
unnamed: D35.2 (A), MX35.2 (ROW)
unnamed: D36.2 (A), MX36.2 (ROW)
unnamed: D37.2 (A), MX37.2 (ROW)
unnamed: D38.2 (A), MX38.2 (ROW), MX101.2 (ROW), MX102.2 (ROW)
unnamed: D39.2 (A), MX39.2 (ROW)
unnamed: D40.2 (A), MX40.2 (ROW)
unnamed: D41.2 (A), MX41.2 (ROW)
unnamed: D42.2 (A), MX42.2 (ROW)
unnamed: D43.2 (A), MX43.2 (ROW)
unnamed: D44.2 (A), MX44.2 (ROW)
unnamed: D45.2 (A), MX45.2 (ROW)
unnamed: D46.2 (A), MX46.2 (ROW)
unnamed: D47.2 (A), MX47.2 (ROW)
unnamed: D48.2 (A), MX48.2 (ROW)
unnamed: D49.2 (A), MX49.2 (ROW)
unnamed: D50.2 (A), MX50.2 (ROW)
unnamed: D51.2 (A), MX51.2 (ROW)
unnamed: D52.2 (A), MX52.2 (ROW)
unnamed: D53.2 (A), MX53.2 (ROW)
unnamed: D54.2 (A), MX54.2 (ROW)
unnamed: D55.2 (A), MX55.2 (ROW)
unnamed: D56.2 (A), MX56.2 (ROW)
unnamed: D57.2 (A), MX57.2 (ROW)
unnamed: D58.2 (A), MX58.2 (ROW)
unnamed: D59.2 (A), MX59.2 (ROW), MX103.2 (ROW)
unnamed: D60.2 (A), MX60.2 (ROW)
unnamed: D61.2 (A), MX61.2 (ROW)
unnamed: D62.2 (A), MX62.2 (ROW)
unnamed: D63.2 (A), MX63.2 (ROW)
unnamed: D64.2 (A), MX64.2 (ROW)
unnamed: D65.2 (A), MX65.2 (ROW), MX104.2 (ROW)
unnamed: D66.2 (A), MX66.2 (ROW)
unnamed: D67.2 (A), MX67.2 (ROW)
unnamed: D68.2 (A), MX68.2 (ROW)
unnamed: D69.2 (A), MX69.2 (ROW)
unnamed: D70.2 (A), MX70.2 (ROW)
unnamed: D71.2 (A), MX71.2 (ROW)
unnamed: D72.2 (A), MX72.2 (ROW)
unnamed: D73.2 (A), MX73.2 (ROW)
unnamed: D74.2 (A), MX74.2 (ROW)
unnamed: D75.2 (A), MX75.2 (ROW)
unnamed: D76.2 (A), MX76.2 (ROW)
unnamed: D77.2 (A), MX77.2 (ROW)
unnamed: D78.2 (A), MX78.2 (ROW)
unnamed: D79.2 (A), MX79.2 (ROW)
unnamed: D80.2 (A), MX80.2 (ROW)
unnamed: D81.2 (A), MX81.2 (ROW)
unnamed: D82.2 (A), MX82.2 (ROW)
unnamed: D83.2 (A), MX83.2 (ROW)
unnamed: D84.2 (A), MX84.2 (ROW)
unnamed: D85.2 (A), MX85.2 (ROW)
unnamed: D86.2 (A), MX86.2 (ROW)
unnamed: D87.2 (A), MX87.2 (ROW)
unnamed: D88.2 (A), MX88.2 (ROW)
unnamed: D89.2 (A), MX89.2 (ROW)
unnamed: D90.2 (A), MX90.2 (ROW)
unnamed: D91.2 (A), MX91.2 (ROW)
unnamed: D92.2 (A), MX92.2 (ROW)
unnamed: D93.2 (A), MX93.2 (ROW)
unnamed: D94.2 (A), MX94.2 (ROW)
unnamed: D95.2 (A), MX95.2 (ROW)
unnamed: D96.2 (A), MX96.2 (ROW)
unnamed: D97.2 (A), MX97.2 (ROW)
unnamed: D98.2 (A), MX98.2 (ROW)
unnamed: D99.2 (A), MX99.2 (ROW)
unnamed: D100.2 (A), MX100.2 (ROW)
unnamed: F1.1, FB1.2
unnamed: J1.A5 (CC1), R1.2
unnamed: J1.B5 (CC2), R2.2
unnamed: R3.1, U1.4 (D-)
unnamed: R4.1, U1.5 (D+)
unnamed: R5.1, U1.43 (PE2/~HWB)
unnamed: R6.2, SW1.2, U1.20 (~RESET)
RGBDIN: D101.3 (DIN), U1.51 (PA0)
ROW0: D1.1 (K), D12.1 (K), D18.1 (K), D23.1 (K), D28.1 (K), D33.1 (K), D39.1 (K), D44.1 (K), D49.1 (K), D54.1 (K), D60.1 (K), D66.1 (K), D72.1 (K), D79.1 (K), D94.1 (K), D98.1 (K), U1.30 (PD5)
ROW1: D2.1 (K), D7.1 (K), D13.1 (K), D19.1 (K), D24.1 (K), D29.1 (K), D34.1 (K), D40.1 (K), D45.1 (K), D50.1 (K), D55.1 (K), D61.1 (K), D67.1 (K), D73.1 (K), D80.1 (K), D84.1 (K), D89.1 (K), U1.2 (PE7)
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

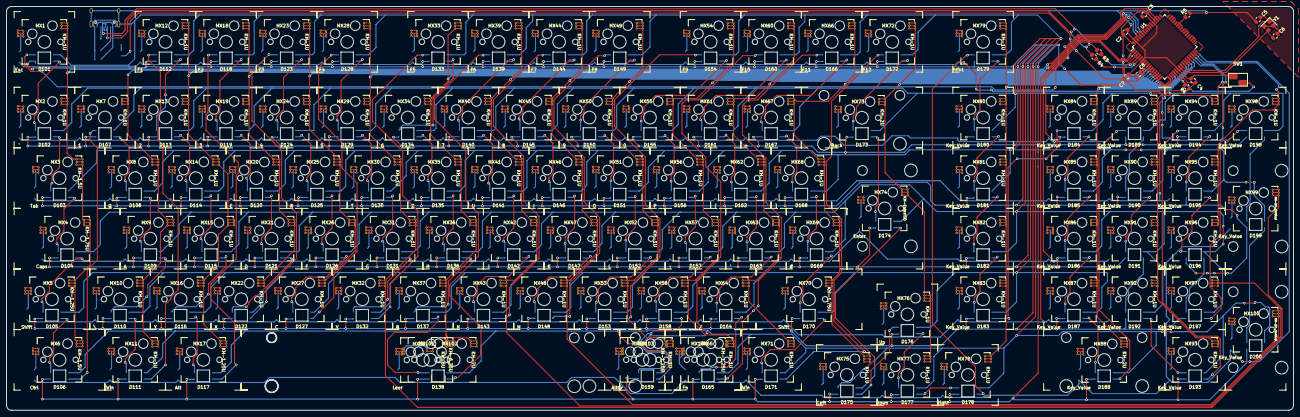
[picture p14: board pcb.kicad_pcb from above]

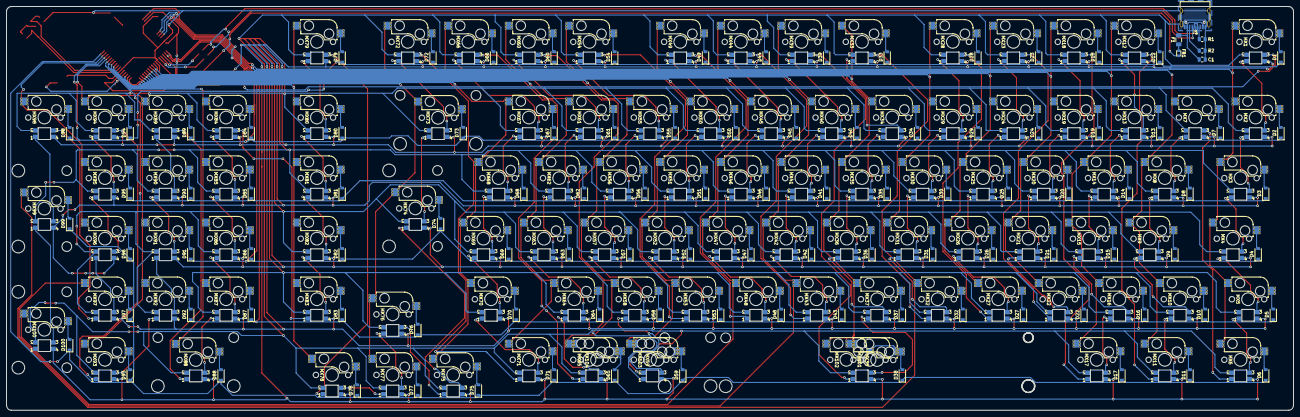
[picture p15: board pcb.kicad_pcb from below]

Board: 2 copper layers, 404.8 x 127.0 mm, 324 parts (106 on the bottom side), 141 nets.

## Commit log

2022-02-14 Added KiCad Project
    [pcb.kicad_pcb, pcb.sch]
2022-03-06 Finished MCU
    [pcb.sch]
2022-03-06 USB Circuit added
    [pcb.sch]
2022-03-06 Finished Matrix
    [pcb.sch]
2022-03-06 Renamed Switches
    [pcb.sch]
2022-03-06 Added Footprints
    [pcb.sch]
2022-04-14 Changed Switches to have no LED
    +Wired left arrow
    [pcb.sch]
2022-04-14 Added LEDs to the Schematic
    [pcb.kicad_sch]
2022-04-14 Submodule, LEDs, Footprints
    [pcb.kicad_sch]
2022-04-14 Started PCB + Changed Footprints
    [pcb.kicad_pcb, pcb.kicad_sch]
2022-04-15 Philipp Spacebar
    [pcb.kicad_pcb]
2022-04-15 Added Enter (Commit Tests)
    [pcb.kicad_pcb]
2022-04-15 start of leds
    [pcb.kicad_pcb]
2022-04-15 Finished Switch Layout
    [pcb.kicad_pcb, pcb.kicad_sch]
2022-04-15 Diode placement, Alternative Bottom Rows
    -New Footprints
    [pcb.kicad_pcb, pcb.kicad_sch]
2022-04-15 Changed Footprint for Ferrite
    [pcb.kicad_pcb, pcb.kicad_sch]
2022-04-15 Placed all LEDs
    [pcb.kicad_pcb, pcb.kicad_sch]
2022-04-16 PCB Size, LED Footprints
    [pcb.kicad_pcb, pcb.kicad_sch]
2022-04-17 coper plates backup Philipp
    [pcb.kicad_pcb]
2022-04-17 Copper Plates Backup (Simon)
    [pcb.kicad_pcb]
2022-04-17 MCU start
    [pcb.kicad_pcb, pcb.kicad_sch]
2022-04-17 Wired Rows and Columns
    [pcb.kicad_pcb, pcb.kicad_sch]
2022-04-17 Revert "Merge branch 'main' of https://github.com/DiomKBS/Diom-75TK"
    This reverts commit d4d5be1e366361c8f7f1bcceadc728d9bff743c0, reversing
    changes made to cc8c22ed399807c67032a22d6e05ce12f162b48f.
    [pcb.kicad_pcb]
2022-04-17 5V and usb
    [pcb.kicad_pcb]
2022-04-17 Rounded PCB Edges
    [pcb.kicad_pcb]
2022-04-17 LED Shenanigans
    [pcb.kicad_pcb, pcb.kicad_sch]
2022-04-17 LED Data Buses finished
    [pcb.kicad_pcb, pcb.kicad_sch]
2022-04-17 Added LED Net
    [pcb.kicad_pcb, pcb.kicad_sch]
2022-04-18 led go brrrr
    [pcb.kicad_pcb]
2022-04-19 change diod
    [pcb.kicad_sch]
2022-04-19 change Crystal
    [pcb.kicad_pcb, pcb.kicad_sch]
2022-04-19 Added missing LED Ground
    [pcb.kicad_pcb]
2022-04-19 gerber and cahnge value of diodes
    [pcb-B_Cu.gbr, pcb-B_Mask.gbr, pcb-B_Paste.gbr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]
2022-04-19 change footprint
    [pcb.csv, pcb.kicad_pcb, pcb.kicad_sch]
2022-04-19 Backplate Stuff
    [plate.dxf, plate.kicad_pcb]
2022-04-20 add tree graphic
    [plate.kicad_pcb]
2022-04-20 Revert "idk"
    This reverts commit e0f5a71326574bffc903f545a908fb671bec7abd.
    [pcb.kicad_pcb]
2022-04-20 Revert "switchj"
    This reverts commit d5a96ddcb071ce4a4afd099785118bfee5e594ee.
    [pcb.kicad_pcb, pcb.kicad_sch]
2022-04-20 Reset Switch updated
    [pcb.kicad_pcb]
2022-04-21 Rough Col and Row wiring
    [pcb.kicad_pcb]
2022-04-21 some silk
    [pcb.kicad_pcb, pcb.kicad_sch]
2022-04-21 Via for Col and Row
    [pcb.kicad_pcb]
2022-04-21 Via updated
    [pcb.kicad_pcb]
2022-04-21 All Rows and Columns connected
    [pcb.kicad_pcb, pcb.kicad_sch]
2022-04-21 LED Data Bus connected
    [pcb.kicad_pcb, pcb.kicad_sch]
2022-04-21 Reset Switch Footprint Updated
    [pcb.kicad_pcb, pcb.kicad_sch]
2022-04-21 Silkscreen Legends updated
    [pcb.kicad_pcb, pcb.kicad_sch]
2022-04-21 Probably Finished
    [pcb.kicad_pcb]
2022-04-21 update submodule
    [MacroBoard.kicad_pcb, MacroBoard.kicad_sch]
2022-04-21 New Diode Placement and Cols and Rows
    [pcb.kicad_pcb, pcb.kicad_sch]
2022-04-21 macro board
    [MacroBoard.kicad_pcb, MacroBoard.kicad_sch]
2022-04-22 makro board
    [MacroBoard.kicad_pcb, MacroBoard.kicad_sch]
2022-04-22 Seperate Sheets, Diode Data, Cols + Rows Finished
    [led.kicad_sch, matrix.kicad_sch, pcb.kicad_pcb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]
2022-04-22 Ground Planes, USB Wiring, MCU Wiring
    [pcb.kicad_pcb]
2022-04-22 LED Diode Placement finished
    [led.kicad_sch, matrix.kicad_sch, pcb.kicad_pcb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]
2022-04-24 LED +5 Wired, COL and ROW Buses nearly finished
    [led.kicad_sch, matrix.kicad_sch, pcb.kicad_sch]
2022-04-24 Roughly finished, Rotary Encoder in Prev
    [pcb.kicad_sch]
2022-04-24 +5V for LED Connected
    [pcb.kicad_sch]
2022-04-24 Fixed all Errors
    Only 1009 Warnings remain :D
    [matrix.kicad_sch, pcb.kicad_sch]
2022-04-24 3D Models
    [EC11E-15SW.STEP, led.kicad_sch, matrix.kicad_sch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]
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2022-04-27 New Connector
    [led.kicad_sch, matrix.kicad_sch, pcb.kicad_sch]
2022-04-27 usb c
    [Unified-Daughterboard_bom_C3.csv]
2022-04-27 Optimized PCB for rounded Tracks
    Also new PCB with rounded Tracks (no errors)
2022-04-30 Now only 2 alternative bottom rows
    6.25U (Three 1U Keys to the right) and 7U (One 1.25U Key and one 1U Key to the right) Space Supported
    Also new rounded PCB
    [matrix.kicad_sch, pcb.kicad_sch]
2022-05-11 datalines and mosfet
    [led.kicad_sch, matrix.kicad_sch, pcb.kicad_sch]
2022-05-11 Relocated JST Connector
    [led.kicad_sch, pcb.kicad_sch]
2022-05-12 change port position
    [led.kicad_sch, pcb.kicad_sch]
2022-05-15 Added Plate Gaskets
    Diom Logo on Plate
    [plate.kicad_pcb]
2022-05-15 Gerber Files
    [plate-B_Cu.gbl, plate-B_Silkscreen.gbo, plate-Edge_Cuts.gm1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]
2022-05-16 changes:\n\n -change zones\n -add mounting holes\n -change via size
    [led.kicad_sch, matrix.kicad_sch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]
2022-05-22 production and CAD preparations
    [EC11 Rotary Encoder Dode Switch-15mm .STEP, LED_SK6812MINI-E v1-mirror.step, LED_SK6812MINI-E.step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]
2022-05-24 Copper Frame on Backplate
    [plate.kicad_pcb]
2022-05-24 New Gerber for Backplate
    [plate-B_Cu.gbl, plate-B_Silkscreen.gbo, plate-Edge_Cuts.gm1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]
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2022-05-24 add Render Files
    [FreeCAD_PCB_withoutFill.FCStd, PCB.blend]
2022-06-19 production?
    still hope
    [led.kicad_sch, matrix.kicad_sch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]
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2022-09-13 Fixed LEDs
    [led.kicad_sch, pcb.kicad_sch]
2022-11-05 New Gerbers, New Rounded
    [pcb-B_Cu.gbr, pcb-B_Mask.gbr, pcb-B_Paste.gbr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]
